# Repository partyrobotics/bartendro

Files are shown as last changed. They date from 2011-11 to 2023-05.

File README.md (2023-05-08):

Introduction
============

Programs for the various systems of the Bartendro drink dispensing robot.

Created by Pierre Michael and Robert Kaye
Copyright (c) Party Robotics 2010-2013

All of the source code in this repository is licensed under the GNU Public License 2.0.
The hardware schematic and layouts are licensed using the Creative Commons 
Attribution-ShareAlike 3.0 Unported license.

The source tree is laid out as follows:

hardware -- schematics and layouts for the dispenser and router hardware boards
firmware -- source code (C) for the dispenser and router boards
scripts  -- scripts to make running the bartendro software easier
tsb      -- legacy code from our old skool drink bot prototyp Tequila Sunrise Bot
ui       -- web interface for the bot, written in python.

These various subdirectories may contain more README and COPYING files.

Downloading updated SD Card images
==================================

In 2021 the SD card images were updated. They can be downloaded here:

https://github.com/partyrobotics/bartendro/releases/tag/v-2021-05-21

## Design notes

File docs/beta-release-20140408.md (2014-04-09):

Upgrade instructions for Bartendro software beta 2014-04-08
===========================================================

This software release is BETA quality, meaning that you may encounter bugs in the software.
Please do not use this for important parties. :)

If you find problems with the new software, please report them here:

https://github.com/partyrobotics/bartendro/issues/new

**REALLY IMPORTANT NOTES -- Please read the following before proceeding!**

* PLEASE READ THE WHOLE INSTRUCTIONS BEFORE YOU BEGIN!
* We recommend using a separate empty 4GB SD Card for this beta release. **WE DO NOT
RECOMMEND THAT YOU OVERWRITE YOUR CURRENT BARTENDRO SD CARD!!**

Download the beta release
-------------------------

To start, download this file:

ftp://download.partyrobotics.com/pub/partyrobotics/bartendro/images/beta-release-20140408.zip

Alternatively, if you know how to use 7zip, you can download this much smaller file:

ftp://download.partyrobotics.com/pub/partyrobotics/bartendro/images/beta-release-20140408.7z

While one of the above files downloads, fire up your Bartendro and go to the options tab
in the admin interface for Bartendro ( /admin/options ). You should do this using a laptop or a PC
so that you can download Bartendro's database and save it to your machine. On the options
screen, look for the Database box and then click on the "Download Database" button. This will cause
the Bartendro database file to be downloaded to your local computer. Save this file in a location
where you can find it later. Ideally, drop it into something like DropBox for safe keeping.

When the download of the software update finishes, extract the .img file by double clicking on
the .zip file. Most modern OSes will extract the .img file and place it into the same directory
where you downloaded the zip file. For the new step, you'll need a separate 4GB SD card like
this one:

http://www.amazon.com/SanDisk-Ultra-Class-Memory-SDSDU-032G-AFFP

We recommend SanDisk (they fail less often) and the speed class 10 -- this will make your Bartendro
run nice and fast. You may also use a larger capacity SD card, but it won't make a real difference 
how Bartendro runs.

Write the image to the new SD Card
----------------------------------

Next, write the image you downloaded onto the SD Card. These instructions cover all the bases for
getting this job done. Please note that you can skip the part about "Downloading an Image", "Choose
your Operating System" and "Choose your distribution". You're going to write the .img file you've 
already downloaded. Other than that, follow these instructions exactly:

http://learn.adafruit.com/downloads/pdf/adafruit-raspberry-pi-lesson-1-preparing-and-sd-card-for-your-raspberry-pi.pdf

Install the new SD Card into Bartendro
--------------------------------------

Once you've managed to write the SD Card, you're ready to swap out the current SD Card for the one
in your Bartendro. IMPORTANT: Turn off your Bartendro. If you fail to turn off your Bartendro before
swapping out the cards, you're going to damage the Raspberry Pi that runs everything. 

**AGAIN: Turn off Bartendro. In fact, unplug it from wall-power!**

If you have a Bartendro 7 or Bartendro 15, it might be easier to perform the next step with Bartendro
set upside down on its head. This next step is somewhat fiddely, due to the limited space inside the
bot.  TIP: Grab a camera(phone) and take a picture of the underside of your Bartendro to see where
each of the black cables connect to. This way you can reconnect all the cables into the proper place.
Bartendro 1 & Bartendro 3 are a cake -- the Raspberry Pi board is easily accessible in the back.

Here is a view of my Bartendro 7's SD Card:

https://www.flickr.com/photos/mayhem/13743267415/

In order to get access to the SD Card, you may need to disconnect a few dispenser cables as I did. Once
you have access to the SD Card, remove the SD Card be sliding it to the right. It should pop right out. But,
be careful! The holder for the SD Card is quite fragile and I've managed to break a Raspberry Pi that way.
Take the existing card and set it aside in some place safe. I would suggest getting a plastic bag if you
don't have an SD Card case handy. Label the bag so you can remember what this SD Card is!

Once you've set aside the old SD Card, insert the newly written SD Card into the SD Card slot in the Raspberry
Pi. Again, be careful to not damage the Raspberry pi. Make sure the card is slid all the way to the left
so that it is seated properly.

Finally, reconnect any dispensers you may have disconnected, taking care to connect the dispensers
back into the appropriate sockets. Refer to the picture you too previously in case you have any questions
as to where each cable should go. Then, turn Bartendro back upright if you turned it upside down. Then connect 
power and boot Bartendro. 

Once Bartendro is up and running, return to your laptop and go back to Bartendro's admin interface and open
the Options page. Ihe Database box, click the red "upload a database" button and follow the instructions to
upload the bartendro.db file that you downloaded earlier. After this Bartendro will reboot and your Bartendro
software update should be complete.

Bartendro is now ready to use again. 

Reporting bugs
--------------

If you find any bugs (issues), please report them here:

https://github.com/partyrobotics/bartendro/issues/new

If you run into trouble during this update, give us a shout here: http://partyrobotics.com/contact-us/

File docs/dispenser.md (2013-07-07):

Documentation for Bartendro Dispenser

Functional overview
===================

The Bartendro Dispenser can dispense liquid with milliliter accuracy and can be 
used in a stand alone system or in combination with a router and other pumps to create a more
complex liquid dispensing system.

The functions this dispenser can perform are:

- Run the pump for a number of milliseconds.
- Run the pump for a number of rotations (or quarters of rotations)
- Set the built-in LED colors and run LED animations
- Estimate the amount of liquid left in a bottle
- Sense when the pump is seizing and shut off power to the motor
- Track use of the pump using number of rotations.

Hardware overview
=================

Bartendro uses a star network topology using RS-232 (serial) communications.
A Bartendro drink bot usually contains a Raspberry Pi (RPI), a router board for communicating 
with dispensers and up to 15 dispensers. Using the router, the RPI can select one dispenser at
a time and communicate with it or communicate in broadcast mode to all of the dispensers at the 
same time. 

While these docs focus on discussing the dispensers, you need to be aware of what the router
does in order to fully understand all of the communication nuances of our dispensers. Because
of the router, each dispenser is programmed with a dispenser id that uniquely identifies a 
dispenser in the system. This id needs to be received from the dispenser at the start of the 
communication with the dispenser.

Each dispenser also contains 4 tri-color LEDs connected to a WS2801 LED driver chip that handles
the PWM functions to set the LEDs to a given color. All LEDs in one dispenser are connected
to one WS2801 chip and cannot be independently addressed. Given that the RPI cannot communicate
with all of the dispensers at exactly the same time, we've included a SYNC signal from the router
to each of the dispensers. This SYNC signal is used to synchronize LED animation patterns
stored in the dispensers. The dispenser changes the color of the LEDs based on the stored
pattern periodically based on the SYNC signal.

Accuracy considerations
=======================

Pumping speed and accuracy are sometimes in conflict. 

For instance, if you are dispensing 10ml via the dispense ticks method at full speed (speed 255), 
you are likely to get about 2ml more output that you asked for. The reason for this is that the
motor requires more time to spin down from full speed once the desired number of ticks is reached.

Rather than forcing one method on all of our users, we ask you to consider the proper handling
of this quirk of our dispensers. We suggest the following methods:

1. The ostrich solution: If you care about dispensing larger volumes and being off by 2ml is not a 
problem, then don't worry about it.

2. The sloppy method: Dispense 2ml less at full speed than you actually plan to dispense. This should
work out ok, but its... sloppy.

3. The slow, but sure method: Reduce the speed to half speed. The "overpour" will be negligible and your
output will be correct, but slower.

4. The corporate american way: Dispense your desired amount at full speed, less 10ml. For the last 10ml,
dispense at half speed. This is how the oil companies ensure they don't give you one cent of gas too much. :)

IMPORTANT NOTE: The above instructions assume that you provide the pump motor 24V. If you provide
less voltage your results may differ and you should test the results accordingly.

Communicating with a dispenser
==============================

After power up, the LEDs in the pumps will turn blue, waiting for communication. If a pump 
starts up and has a solid red color, its is missing a dispenser id that needs to be 
programmed into eeprom. See eeprom section for more information on this.

To initiate communication, the user should send the question mark character '?' to the pump. 
The dispenser will respond with a one byte response that is its dispenser id. The dispenser 
will continue to respond to '?' characters until it receives a 0xFF character, indicating that 
the dispenser user has captured the dispenser id and communication can start. The user should 
save the dispenser id as it will be required to address the dispense in subsequent communication.

Once the dispenser is ready for communication it will display its "idle" LED pattern which is a 
rainbow color changing pattern. At this point the dispenser is ready to receive a packet
of data. Now the user may send a packet of data to the dispenser. The dispenser will respond
with either a single byte ACK code, or a complete packet, depending on the type of
packet that was sent.

Each packet contains a destination field, which is the dispenser id that was captured
in the beginning of communication with the dispenser. While this may seem silly in a single
dispenser setup, its important when more than one dispenser is used in conjunction with 
a router. All packets sent from the router are sent over one serial TX line to ALL dispensers
connected to the router. All dispensers receive the packets and if the packet is not
marked as a broadcast packet or marked with its dispenser id, the dispenser will ignore
the packet. If a dispenser receives a packet that is a broadcast packet it must take the
appropriate action and NOT SEND a response. Broadcast packets should NEVER be replied to. 
If a dispenser receives a packet with its dispenser id, it must take action and then 
send a response to the user. Depending on the packet type, a response can either be 
a single character ACK code, or a complete packet in response.

For more information on how packets are structured, packet types and if they require
a response, see the detailed packet sections below.

Packet structure
================

Packets are comprised of two sections:

 * Header: 2 characters, always 0xFF 0xFF
 * Packet body, which is 7 bit data escaped, 10 bytes long

This packet body must be encoded into 7 bit data, so that the MSB of any data in the packet will
never be set. This allows the dispenser to clearly identify a packet header, which is the 
only data to ever have the MSB set in an entire packet. For details on how to encode data
to 7 bits, please see firmware/common/pack7.c[|h]. 

The data in the packet, when unpacked is 8 bytes long:

 * unsigned byte: destination dispenser id -- the dispenser id discovered during the 
   communication setup or BROADCAST_DEST.
 * unsigned byte: packet type -- one of the packet types described below
 * 4 bytes of payload data -- Either a 32 bit value, 2 16 bit values or 4 8 bit values.
 * unsigned 16 bit word: 16 bit CRC value calculated for the destination, type and payload
   value. For the details of this algorithm, see the function crc16_update() in
   ui/bartendro/router/driver.py

Sending packets
===============

Packets should be sent to the dispensers with a baud rate of 9600, no party and 1 stop bit.
After sending 10 bytes, the user should wait until the dispenser sends a response. Most packet 
types will get a single byte ACK code response and some will get a complete packet as a response.
Packets that receive a full response are:

 * PACKET_IS_DISPENSING 
 * PACKET_LIQUID_LEVEL
 * PACKET_UPDATE_LIQUID_LEVEL
 * PACKET_SAVED_TICK_COUNT
 * PACKET_GET_LIQUID_THRESHOLDS

All other packet types will receive a simple ACK code, consisting of one of the following:

 * 0 - PACKET_ACK_OK       -- packet received OK and acted upon
 * 1 - PACKET_ACK_CRC_FAIL -- packet data was corrupt and was not executed
 * 3 - PACKET_ACK_INVALID  -- the packed was improperly packed to 7 bits and did not yield 8
                              bytes of packet data.
 * 4 - PACKET_ACK_INVALID_HEADER -- an incomplete header (only one 0xFF character) was received
 * 5 - PACKET_ACK_HEADER_IN_PACKET -- An header character (0xFF) was received in a packet, 
                                      which is invalid.

For any packet that requires a complete response (any packet that returns data and not just an 
ACK) the dispenser will respond by sending a complete packet in response. Once this packet has
been received by the user, a single character ACK, as described above, must be sent to the
dispenser.

Packet types
============

The following packets can be set to/from the dispenser:

* PACKET_PING -- A diagnostic to see if the dispenser is alive. No action is taken. Contains
  no data payload.
* PACKET_SET_MOTOR_SPEED -- Turn the motor on at a given speed. The max speed is 255, which 
  should be suitable for most applications. If you'd like the dispenser to turn more slowly, 
  you can give it a slower speed. Slower speeds can be useful for dispensing smaller quantities
  of liquid or where more fine grained control is required. We recommend to not set the speed
  below 64, since at that speed the motor can barely overcome the friction to turn the pump.
  To turn the pump off completely, set the speed to 0. Once this command is initiated, the 
  dispenser will immediately return an ACK and it will not wait for the dispense function to 
  complete. Data payload is motor speed as a 8 bit unsigned int in the first byte and wether
  or not to enable over current sense in the second 8 bit unsigned int.
* PACKET_TICK_SPEED_DISPENSE -- Dispense for a certain number of ticks at a given speed. Dispenser
  rotation is measured in "ticks" which are generated by magnets moving over hall sensors in the 
  dispenser. There are 4 hall sensors, so it takes 4 ticks for the pump to make one full turn. 
  This function is the most accurate way to dispense a liquid. We've determined that the pump 
  dispenses 1 milliliter in 2.78 ticks. Once this command is initiated, the dispenser will 
  immediately return an ACK and it will not wait for the dispense function to complete. The number
  of ticks to dispense is an unsigned 16 bit payload and the speed to dispense (max speed is
  255!) is the second unsigned 16 bit payload.
* PACKET_TIME_DISPENSE -- Dispense for a certain number of milliseconds. The 32 bit payload
  determines the number of milliseconds the pump should run for. Tick counting is completely
  ignored with this command. Payload is a 32 bit unsigned integer.
* PACKET_LED_OFF -- Turn off the LEDs in the dispenser. No payload.
* PACKET_LED_IDLE -- Display the "idle" pattern in the dispenser. No payload.
* PACKET_LED_DISPENSE -- Display the "dispense" pattern on the LEDs. No payload.
* PACKET_LED_DRINK_DONE -- Display the "drink done" pattern. No payload.
* PACKET_IS_DISPENSING -- This function asks the dispenser if it is still dispensing. Since
  the dispense commands return immediately and don't wait for the dispense to complete,
  the user needs a method to determine if a dispense is complete. This call enables that.
  This packet requires a complete packet response. There is no data payload for the
  request sent from the user, but the dispenser responds with a boolean response (is dispensing)
  in the first byte of the payload and if the over current sensor has been triggered in the 
  second byte of the payload.
* PACKET_LIQUID_LEVEL -- If a dispenser is equipped with a liquid level sensor, this call
  will return the liquid level saved in the dispenser's ram. Liquid levels are not read on 
  the fly -- instead a stored value will be returned to the user. To update the stored value 
  with the current value use the PACKET_UPDATE_LIQUID_LEVEL command. The liquid level in the 
  bottle (or whatever vessel might be used) is expressed as 10 bit value (0 - 1024). Liquid
  level sensors are sensitive devices that require a minor amount of calibration. Each liquid
  level sensor may have a slightly different idea of what "empty" means. For more information
  on how to interpret these values, please see the section "liquid level sensors". If the
  dispenser is not equipped with a liquid level sensor, the values returned by this command
  are undefined. This packet requires a full packet response. Packets sent to the dispenser
  contain no payload. Packets sent from the dispenser contain a 10 bit value in the
  first 16 bit value in the payload.
* PACKET_UPDATE_LIQUID_LEVEL -- Use this command to force the dispenser to update the 
  current liquid level. We recommend that you let at least 5ms pass between updating the 
  liquid levels with this command and reading them with PACKET_LIQUID_LEVEL. No payload.
* PACKET_ID_CONFLICT -- If two dispensers connected to one router have the same dispenser id,
  it creates an ID conflict. This command turns the pump LEDs red and cause the pump to
  do nothing until it is reset. No payload.
* PACKET_LED_CLEAN -- Set the LEDs to the "clean" pattern. No payload.
* PACKET_SET_CS_THRESHOLD -- This command sets the threshold value at which the motor is 
  considered to be seized and should be turned off. This can happen when hoses get old or
  are otherwise obstructed. To prevent the motor from burning out, the current sensor
  determines when a motor is working too hard and shuts off the pump. The default value
  programmed into the dispensers should suffice for most uses. For more information see
  the section "over current protection". The current sense limit should be given in 
  the first 16 bit value of the payload.
* PACKET_SAVED_TICK_COUNT -- This command retrieves the tick count saved in the dispenser's
  eeprom memory. It tells you how many ticks (turns if you divide ticks by 4) the dispenser
  has turned since the tick counter was reset. This feature is to measure hose life and to give
  the user of the dispenser an idea when the hoses inside the pump need to be replaced. This
  packet requires a full packet response. Packets sent to the dispenser contain no payload. 
  Packets sent from the dispenser contain a 10 bit value in the first 16 bit value in the payload.
* PACKET_RESET_SAVED_TICK_COUNT -- This command resets the stored tick count in the dispenser's
  eeprom memory. This value should only be reset when the hoses inside the dispenser have been
  changed. No payload.
* PACKET_GET_LIQUID_THRESHOLDS -- This command is used to query the liquid out thresholds stored
  in the dispenser's eeprom memory. This packet requires a full response and the response packet
  will contain two 16 bit values: "low" threshold and "out" threshold. For more information
  on liquid level thresholds, please see the section "liquid level sensors". The first
  16 bit value of the payload is the "low" threshold and the second 16 bit value is the "out"
  threshold.
* PACKET_SET_LIQUID_THRESHOLDS -- This command sets the liquid level thresholds. Two 16 bit 
  values for "low" threshold and "out" should be contained in the packet. For more information
  on liquid level thresholds, please see the section "liquid level sensors".
* PACKET_FLUSH_SAVED_TICK_COUNT -- This command should be sent to the dispenser before shutting 
  down the dispenser. The dispenser keeps track of the current tick count in RAM and only 
  flushes it to eeprom periodically to prevent the eeprom memory from wearing out. To ensure 
  that the accurate tick counts are stored in the pump, make sure to call this command before 
  shutting down the dispenser. No payload.

Deprecated commands:

* PACKET_TICK_DISPENSE -- Dispense for a certain number of ticks. Pump rotation is measured in
  "ticks" which are generated by magnets moving over hall sensors in the dispenser. There
  are 4 hall sensors, so it takes 4 ticks for the pump to make one full turn. This function
  is the most accurate way to dispense a liquid. We've determined that the pump dispenses
  1 milliliter in 2.78 ticks. Once this command is initiated, the dispenser will immediately
  return an ACK and it will not wait for the dispense function to complete. The number
  of ticks to dispense is an unsigned 32 bit payload, but only the 16 bits of data will be used.
  This command is deprecated in favor of the PACKET_TICK_SPEED_DISPENSE that allows the user
  to specify the speed with which to dispense.

EEPROM
======

The EEPROM of the Atmel atmega168a micro-controller contains the following pieces of
data:

   offset     data type         data
   0          8 bit unsigned    Dispenser id
   1          32 bit unsigned   Run count in ticks
   5          16 bit unsigned   Liquid "low" threshold
   7          16 bit unsigned   Liquid "out" threshold

To get a working dispenser, you will need at least to minimally write a dispenser id 
into the first byte into eeprom RAM. This can be any value but 0 or 255. 

Dispensers shipped from PartyRobotics have this dispenser id set. You can set another
dispenser id (chosen randomly) by running the script in /firmware/dispenser/pump.sh

Resetting the dispenser
=======================

To reset the dispenser, the user needs to hold the RESET line high for at least 1ms. This will
do a software reset that causes the dispenser to stop what it is currently doing and
enter the address discovery mode as it normally would on startup.

Liquid level sensors
====================

The liquid level sensors that are available for our dispensers allow the dispenser to
estimate the amount of liquid left in a bottle. The "liquid level" sensors are really
differential pressure sensors that measure the difference between ambient air pressure
and a liquid level hose that rests in the bottle. The liquid in the bottle exerts a tiny
amount of pressure on the hose and there for on the sensor. As the liquid level in the
bottle drops, the pressure approaches the ambient pressure. Once the pressure exerted
on the hose is equal to ambient pressure, the bottle is empty. 

Care should be given to never empty a bottle fully, because if the intake hose sucks
air while dispensing, an inaccurate dispense occurs. To avoid this, the liquid "out"
threshold should be set conservatively so that the dispenser will consider a bottle to
be empty before it is actually empty.

These sensors are sensitive devices that require some calibration. Even at ambient 
air pressure, not all sensors are going to return the value absolute value. Depending on
how you plan to use the pressure sensors we encourage you to read the pressure sensor
readings at different liquid levels to get acquainted with how the sensor works.

Over current protection
=======================

Each dispenser also comes equipped with an "over current sense" circuit. This
circuit estimates the amount of current that the motor in the dispenser consumes. If for
some reason the motor binds up and consumes large amounts of current, the dispenser
stops the motor and flashes the red LEDs quickly. At this point the dispenser refuses
to engage the motor again until the dispense has been reset. 

Empirical testing has shown that the default value of 465 works well for the motor
running at full speed. You can provide different current sense threshold values
using the PACKET_SET_CS_THRESHOLD command.

Color error codes
=================

The dispenser's only real form of end-user feedback is the color of the dispenser. The
following colors/animations are programmed into the stock dispenser:

* Solid RED at startup: id conflict
* Solid BLUE at startup: ready for communication, waiting for user to initiate 
  communication.
* Solid GREEN: A 0xFF character has been received after communication startup. The
  dispenser is now waiting for the first command from the user.
* Rainbow color animation: idle mode. The dispenser is waiting for commands from the user.
* Red <-> blue color animation: Dispenser is dispensing liquids.
* Pulsing green color animation: Dispsener is done dispensing liquids.
* Pulsing purple color animation: Dispenser is currently being cleaned. This mode really
  only has significance in the context of a larger setup where the RPI can execute
  a clean cycle using multiple dispensers.

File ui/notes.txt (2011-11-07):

Feature improvements:

- RBG Led per dispenser, programmed via SPI
- Allow a default size of a drink. (an 8oz sherpentine would be trouble!)
- Support quadarture input from the motors
- PWM support for driving motors
-

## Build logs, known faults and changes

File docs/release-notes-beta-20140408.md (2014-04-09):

Release notes for the beta version of 2014-04-8
===============================================

This is our first post-kickstarter software release. We've added a few critical new features, improved
the UI and added support for the new V3 Dispensers that will be shipping soon. 

We've made the changes listed below. If you would like to try out these changes, please see our upgrade
instructions:

https://github.com/partyrobotics/bartendro/blob/master/docs/beta-release-20140408.md

User facing features:

- We've added a "I'm feeling lucky button"
- UI consistency improvements: General improvements. Green buttons indicate that some action will occur when pressing this button!
- Minor UI tweaks and layout improvements
- Improved Shots UI, including allowing users to switch between cocktail and shot mode
- Improved trending drinks menu, giving a view of the last 12 hours, 3 days, 1 week and all time. Drinks are now clickable links to allow users to examine the drinks on the drink screen.
- For dispensing small amounts of liquids, turn the pumps slower for more accurate dispensing

Admin facing features:

- Bartendro logo goes to admin screen
- Taster button on drink designer -- this is really handy for making new drink recipes.
- Improved clean cycle that runs all pumps for 15 seconds. Bartendro 15 can clean the pumps on the left side indepdenently from the pumps on the right side.
- Rewritten Bartendro Mixer, which is the heart of Bartendro. This should fix a number of liquid level bugs and give better overall stability
- If v3 dispensers are installed, then a "reverse" button appears on the dispenser admin page.
- Display network IP addresses that Bartendro has on the options screen
- Added an option wether or not to show the shots interface.
- Added an option wether or not to show the "I'm feeling lucky!" button
- Used better visual cues in the dispenser view to show the liquid level for each dispenser (if enabled)
- Improved wording of the database upload/download feature

Firmware changes:

- Created updated firmware for v3 Dispensers.
- v3 Dispensers will be able to run pumps in both directions.
- Implemented version checking in firmware

Issues fixed in this release
----------------------------

The following issues have been closed for this release:

https://github.com/partyrobotics/bartendro/issues?milestone=3&page=1&state=closed

Issues still open before release:

https://github.com/partyrobotics/bartendro/issues?milestone=3&state=open

If you find any problems with this release, please report them here:

https://github.com/partyrobotics/bartendro/issues/new

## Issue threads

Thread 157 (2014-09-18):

Intermittent Proper Dispenser Detection

pmich, 2014-09-18:
Someone has mentioned that their bot does not detect all their dispensers 100% of the time. Out of 15, sometimes it detects 14, or 13, or 12. They have to restart many many times for the bot to detect all 15, but in the end it usually works. After much experimentation, I've actually been able to recreate the bug on a brand new router board. It is still intermittent in nature, but it happens more often than not. My setup is B15 with 2 v3 dispensers with IDs: B3 and AB. The first symptom is that on power up the dispensers flash blue 3 or 4 times, then turn red. However, the dispensers always get into the color fade mode once the bot is booted, so that's confusing because it seems like everything is ok. Once I go into the debug menu I see that the the IDs are conflicting and that dispenser v2 was detected.
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
The dispensers work fine on another board, and if plugged in individually, their ID value is more often read correctly in the debug screen. If both dispensers are plugged in, it seems that about 30% of the time both dispenser IDs will be read correctly, otherwise they will display a conflict with ID 63 and v2 detection.
I decided to capture with a logic analyzer to see what was going on. I've reduced down to a single dispenser, and this is what it looks like on startup (orange is TX from Router, red is TX from dispenser):
After a faulty start, this is what it looks like on when I hit 'reset dispensers' from the dispenser page:
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
This is what it looks like when I hit 'test dispensers' in the debug page:
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
On boot (zoomed on the very first thing):
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
On boot (zoomed all the way out):
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

After a power cycle, I got a different result.
On boot it actually got one of the IDs correct:
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
The is what 'test dispenser' from the debug page produces:
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

I know we had a software bug at one point that was timing related, but I don't know if this is similar, I'd love to get your thoughts.

Other than chucking this in the dead router board pile, is there some test to further verify the state of the router board and know that it really is bad, and more importantly, how do we test for a problem like this before we ship hardware out? Should / could we make the dispensers display a different pattern if their ID is never read correctly by the router?

pmich, 2015-01-10:
This issue has been resolved. The dispensers were found to be entering into text-mode inappropriately. A dispenser firmware update requiring 3 consecutive '!' to get into text mode did the trick.

robotskirts, 2015-10-09:
My machine is exhibiting this behavior. How do I update the dispensers?

partyrobotics, 2015-10-13:
Hi Eliot,

Please follow the instructions here:
http://support.partyrobotics.com/Guide/Re-programming+a+Dispenser/13

Best,
-Pierre

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

nighteagle1974, 2017-04-27:
Hello,

so the last dispenser-firmware linked in the above post is older than the post from pmich tell us the trick is to have 3 consecutive "!" to get into Text-Mode. I have compared the Sources from 2015 and 2016 all the same except the LED-Swapping and Software-Revision-ID.

I have the same behaviour with the newer Firmware from Oktober 2016. I have compiled with the raspi2 and avr-gcc and avrdude and program the dispenser are fine. Set ID also fine... Solder Jumper to Version 4 and boot bartendro pumps are recognized as Version 4.. only on the first Slot.
I use for testing only two pumps on Slot 1 and Slot2 both Revision 4 with firmware from Git.
But often the Pumps are not recognized in the Bartendro-Debug Window, when i press button dispense 10ml under Dispenser Menue then sometimes the pump do not start and Error 502 come back. In debug window i see Dispenser V2 detection of first pump. If i change the pumps the next time also first pump detect V2. So here is an bug by detection the First Pump? Slot 1?

To prevent Text-Mode swapping ( we only need the binary-Mode for communicate with the router?) can i change something on the dispenser-sources? Deactivate Text-Mode?

Regards

nighteagle1974, 2017-04-28:
Hello again,

so i have a look into the Sources of the Router.

1. I see the Baudrate is not correct calculated:
#define UBBR             (F_CPU / 16 / BAUD - 1)
Here 52,08
See in Datasheet Atmel:
((F_CPU + UART_BAUD_RATE * 8L) / (UART_BAUD_RATE * 16L) - 1)
Here 51,58

2. Router.c
For what you use the g_reset ?
I see is writing High and Low but is not use for some logic?
Then if we don't use the g_reset we don't need this:
`            cli();
            reset = g_reset;
            sei();

            if (reset)
            {
                cli();
                g_reset = 0;
                sei();
                break;
            }`

Because we break the ISR for an nonsense writing of g_reset ?

I see the echo_dispenser is call by an ISR. So on the beginning of  the ISR the reti is disable ISR and enable ISR at the end. If you call the echo_dispenser in the ISR:
`ISR(PCINT0_vect)
{
    echo_rpi();
    echo_dispenser();
}`

There is no break of these function like you wrote here:
`void echo_dispenser(void)
{
    volatile unsigned char *group;
    uint8_t pin, state;

    // capture a local copy of g_dispenser to guarantee the next two lines use the same value
    // (interrupt could come between the two and change g_dispenser, I think? Depends on interrupt
    // rules. I don't *think* this is an issue, but it would be a rare enough failure case that
    // it would be near impossible to debug.)
    uint8_t disp = g_dispenser;

    group = dispenser[disp].group;
    pin = dispenser[disp].pin;

    state = *group & (1 << pin);

    if (state)
	// Bit 0 go High
        sbi(PORTB, 0);
    else
	// Bit 0 go Low
        cbi(PORTB, 0);
}
`
I think we don't need write globale variable to an locale variable into an ISR-called Function.

What your thoughts about my Points?

nighteagle1974, 2017-04-28:
Looks like the Code-Comment is not working here on this Github?
`Test Code-Comment`

nighteagle1974, 2017-04-28:
Looks like the Code-Comment is not working correct here on the Github?

mayhem, 2017-04-28:
g_reset is used to reset the each pump on the bot -- it is a critical function. A message comes in via I2C to reset the bot which gets acted on here:

   https://github.com/partyrobotics/bartendro/blob/master/firmware/router/router.c#L240

Why do you think the ISR is broken by writing to a variable? The variable is defined as volatile, so I see no problems with it. Have you tried any of the changes you are suggesting? Do they improve things?

nighteagle1974, 2017-04-28:
No i don't think ISR is broken.
The Programmer write here:
// capture a local copy of g_dispenser to guarantee the next two lines use the same value
// (interrupt could come between the two and change g_dispenser, I think? Depends on interrupt
// rules. I don't *think* this is an issue, but it would be a rare enough failure case that
// it would be near impossible to debug.)

But does is not correct because the ISR is deactivated bei reti from CPU, you don't need to write the global to an locale in an ISR-Called function.
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
nighteagle1974, 2017-04-28:
Okay.. i see now more..

You have an For-Loop to test reset-variable.. if there is High you break the Loop and go to one Level higher and there is the reset-dispenser functions. Okay i understand.

mayhem, 2017-04-28:
"3.3V Pegel" bissu deutsch? :)

long Cables 0,5m -- yes, I've heard of this problem before of bots that do not use Bartendro cases (ergo longer cables are needed). I would love to hear if this makes any difference in communication reliability. Also, do you have problems while the motors are running (interference) or also when motors are not running?

nighteagle1974, 2017-04-28:
Ja Deutsch.. meinte 3,3V Level :-)

mayhem, 2017-04-28:
Klar, schon kapiert. :)

nighteagle1974, 2017-04-28:
Yes have Problems like pierre wrote above. I 'm looking now for.. first 3,3V level is an problem by cables longer 0,5m. Sometimes Pumps not recognized correct. I have to restart bot many times. Actually i will check communication with logic analyzer.

nighteagle1974, 2017-04-28:
Toll, wenn ihr alle Deutsch seid. Warum sieht man das nicht :-)

mayhem, 2017-04-28:
Ich bin deutsch, aber auch nur der einzige. :) Und ich habe auch zu lange in Kalifornien gelebt...

I would love to hear if you can find problems on the logic analyzer -- I've never had a Bartendro with longer cables, so I've never really seen this problem.

nighteagle1974, 2017-04-28:
Cool... bei Arnie?

Yes  the 3,3V is an Problem for UART with cables. If you have some other cables it may can work but in other situations it can't work correctly. This is why some people have problems and some not -  i think.

mayhem, 2017-04-28:
Ja, bei Arnie. :)

But, I do wonder if the UART calculation will make any difference -- I'd love to hear about it.

mightybigcar, 2017-04-28:
OK, I'm just an embedded software guy who can't even reliably read a schematic, but the I2C discussion reminds me of something I've bumped into in previous projects with long I2C lines (that is, over about 100mm).  In my experience (which may or may not apply here), for long distance, I2C gets finicky about trace/cable resistance, capacitance, noise, and so on.  You may need to add an active pull up on the line, or tweak the UART configuration (if possible), or switch to shielded or twisted pair cables, or some combination of these.  Anyway, I think this tends to confirm nighteagle1974's concerns about 3.3V on the longer cables - the next thing I'd do there is bring in a EE to check that and maybe add a pull-up (or try to configure stronger pull-up on the UART).

nighteagle1974, 2017-06-23:
Moin Robert,

habe wieder etwas Zeit gefunden für den  Bartendro.
Habe Einges verändert.. jetzt geht es wohl gut... zumindest keine
Störungen mehr in der kommunikation.

Eine Frage kurz zur Software.. Ui wenn man Coktails selber erstellt was
bedeutet dann die Angabe "Parts" für die einzelnen Zutaten?
Sind das cl oder Prozente von der Gesamtmenge die man ja einstellen
kann, bei mir 150ml Drinkgröße?

Wobei das ja auch nicht passt.. dann müssten ja immer im Ergebnis 10
parts rauskommen..
Gibt ja auch Cocktails die haben 12 parts insgesamt... Irgendwie blicke
ich es nicht.

Grüsse,

Borris

Am 28.04.2017 13:42, schrieb Robert Kaye:
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

nighteagle1974, 2017-10-21:
Moin,

sag mal kannst du mir ev. weiterhelfen bei der Frage wo in welchen Files
ich suchen muss, dass ich die dosierten Mengen der Ingredients finde?
Also irgendwo wird ja auch für das Trending die dosierten Mengen
kalkuliert!?

Ich möchte die dosierten Mengen speichern und von einem vorher
festgelegten Wert abziehen.

z.B. Alle Zutaten sind in 1L Flaschen - dann setze ich eine Variable für
jede Zutat i.e.   bootleSizeIDn = 1000ml; (n=1-15)
Dann wenn ein Drink gemacht wird - sind ja die Dosiermengen bekannt -
also ziehe ich die jeweiligen dann von der bootleSizeIDn ab.

Bei einem Shot dann einfach 1000ml -30ml = 970ml also hat bootleSizeIDn
dann irgendwo nur 970ml.
Damit könnte man dann eine Grenze setzen wenn bottleSize unter 100ml
fällt, das dann eine Meldung kommt das die Flasche gewechselt werden muss.

Das scheint mir einfacher und zuverlässiger als der Liquid-Sensor zu sein.

In dem Forum bzw. Answer-Bereich passiert so Wochenlang nichts :-(

Grüsse,

Borris

mayhem, 2017-10-24:
> Das scheint mir einfacher und zuverlässiger als der Liquid-Sensor zu sein.

Das stimmt — das ist uns erst viel zu spät aufgegangen.

Leider ist diese feature etwas mehr arbeit — die datenbank muss erweitered werden und neue benuzter oberflächen müsse gebaut werden…

Hier ist aber ein guter anfang:

  https://github.com/partyrobotics/bartendro/blob/master/ui/bartendro/mixer.py#L91

Closed 2015-01-10.

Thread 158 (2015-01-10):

Database Upload Not Working Properly

pmich, 2015-01-10:
Several weeks back I added many ingredients and drinks to my bot and downloaded bartendro.db to my DropBox account. I renamed the file to be bartendroDec2014.db. Today I tried uploading that database file from the options tab. After, the file is uploaded, I get a message saying that the new database file has been successfully uploaded. However when I go to the drinks page, the new drinks are not present. Also, when I go back to the 'upload database' button, it says that the current database file is bartendro.db instead of bartendroDec2014.db like it should be. I've tried 'save and reboot' from the options screen, and I've even tried naming the file back to bartendro.db and uploading that, but all the newly added stuff still doesn't show up. I could've sworn this worked before. Thoughts?

OnkelOlli, 2015-01-10:
After adding new drinks and ingredients, and saving every time, you need to
reboot via the options menu. Then, the additions are used correctly and
will show up in the menu, and only then you can export the new  database.
If you do not reboot, somehow the old settings will be exported.
Greetings, Olli
 Am 10.01.2015 21:49 schrieb "pmich" <notifications@github.com>:

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

nighteagle1974, 2015-12-04:
Hi,

have somewhere an working rpi B+ image?
I think the Image is onyl for RPI B old Version and ist not booting for an B+ RPI.

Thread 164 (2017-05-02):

Liquid level sensor triggered for one ingredient, breaks all dispensing.

pmich, 2017-05-02:
Garran: I am trying to use the liquid level sensors on my Bartendo, but I am running into an issue. If one ingredient runs out it won't let me make any of the drinks. It gives a message saying "Bartendro has hit a snag and can't make drinks right now." Do you know what is going on here? Thanks!

Pierre: Might be worth checking the calibration values and making sure they're sane. Also, make sure that the ingredient that's running out (pretend it's vodka) isn't used by every other drink in the menu.

Garran: Yeah, the values are good. I can look at the dispensers and it shows that only one ingredient is empty (pretend it is vodka). It removes all drinks which require vodka from the menu. When I try to dispense a drink which doesn't contain vodka it lets me adjust the drink and when I hit pour it flashes the "now serving" popup which is immediately replaced with a message "Bartendro is broken. Bartendro has hit a snag and can't make drinks right now. Sorry!" I have tried power cycling it, and that doesn't change anything.

RPI B v. 1
software version is 20140501

ggossage, 2017-05-02:
The ingredient which has run out does not appear in the shots menu, which makes sense. All other ingredients CAN be dispensed from the shots menu. It is only the mixed drinks which can't be dispensed.

ggossage, 2017-05-03:
Updated software to 20151103. Issue appears to behave exactly the same as before.

Debug log:

Bartendro start up sequence:
Opening /dev/ttyAMA0
Done.

Opening I2C bus to router
Done.
Discovering dispensers
port 0:
  E7 E7 E7  -- Found dispenser with pump id E7, index 1
port 1:
  33 33 33  -- Found dispenser with pump id 33, index 2
port 2:
  BE BE BE  -- Found dispenser with pump id BE, index 3
port 3:
  61 61 61  -- Found dispenser with pump id 61, index 4
port 4:
  87 87 87  -- Found dispenser with pump id 87, index 5
port 5:
  F1 F1 F1  -- Found dispenser with pump id F1, index 6
port 6:
  29 29 29  -- Found dispenser with pump id 29, index 7
port 7:
port 8:
port 9:
port 10:
port 11:
port 12:
port 13:
port 14:
Detected dispensers version 2. (Only checked first dispenser)
mixer.check_liquid_levels: check levels
dispenser 0 level: 71 (stored: 0)
dispenser 1 level: 150 (stored: 0)
dispenser 2 level: 123 (stored: 0)
dispenser 3 level: 157 (stored: 0)
dispenser 4 level: 152 (stored: 0)
dispenser 5 level: 139 (stored: 0)
dispenser 6 level: 114 (stored: 0)
Checking levels done. New state: 0
mixer.check_liquid_levels: check levels
dispenser 0 level: 72 (stored: 0)
dispenser 1 level: 149 (stored: 1)
dispenser 2 level: 122 (stored: 1)
dispenser 3 level: 156 (stored: 1)
dispenser 4 level: 153 (stored: 1)
dispenser 5 level: 139 (stored: 1)
dispenser 6 level: 113 (stored: 2)
Checking levels done. New state: 0
Current state 6, event 0. No next state.

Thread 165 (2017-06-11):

Change in LED lights

sdnavin, 2017-06-11:
Is it possible to take control of the LED lighting color?

mayhem, 2017-06-12:
Only via reprogramming the firmware on the pumps, which needs to be done in C and requires a firmware programmer. (overall not an easy task, sadly)

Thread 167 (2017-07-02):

Liquid level sensor

sdnavin, 2017-07-02:
Hi,
I want to know how can i install the liquid level sensor and how the connection works , Please guide me on this.

pmich, 2017-07-05:
Please view instructions here:
http://support.partyrobotics.com/Guide/Installing+a+Liquid+Level+Sensor/11

sdnavin, 2017-07-06:
Hi @pmich This instructions is fine, We did this already but we have problems in that

The current Setup is we have two tubes going to the input drink, One from liquid level sensor and another from the dispenser IN. I believe this setup is fine, Now when i try setting the liquid level in the interface, the value i am getting - "4" all the time.

Debug log as follows :

Detected dispensers version 4. (Only checked first dispenser)
mixer.check_liquid_levels: check levels
dispenser 0 level: 4 (stored: 0)
Checking levels done. New state: 0
mixer.check_liquid_levels: check levels
dispenser 0 level: 4 (stored: 0)
Checking levels done. New state: 0
send_packet: Invalid ACK code 255
Failed to read liquid level threshold from dispenser 1

pmich, 2017-07-06:
The order of operations matters. You should slowly insert the dry tube (after it has already been attached to the liquid sensor), into the liquid, this is how you build positive pressure relative to ambient.

In the Liquid Sensor tab of the admin UI, you should be able to calibrate the value and see it on the spot, if you move the height of the tube relative to the liquid and you don't see calibration value changing, then there's a chance that the sensor is not plugged in all the way, or it is possibly damaged in some way.

If you have a multi-meter, you can measure the output voltage on pin 1 (while it is plugged into the dispenser and powered) and see if the sensor is functional.

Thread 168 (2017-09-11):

Got this error while installing bartendro

jaysonvalentino, 2017-09-11:
Traceback (most recent call last):
  File "./bartendro_server.py", line 118, in <module>
    app.driver.open()
  File "/home/pi/Desktop/bartendro/ui/bartendro/router/driver.py", line 173, in                                                                                                                                                              open
    data = self.ser.read(3)
  File "/usr/lib/python2.7/dist-packages/serial/serialposix.py", line 460, in re                                                                                                                                                             ad
    raise SerialException('device reports readiness to read but returned no data                                                                                                                                                              (device disconnected?)')
SerialException: device reports readiness to read but returned no data (device d                                                                                                                                                             isconnected?)

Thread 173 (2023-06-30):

Master Password ?

NielsBar, 2023-06-30:
Hey,

 I hope you are well. I have a problem before Corona, I changed the password in the software and forgot it and unfortunately I didn't write it down. Is there a master password or can I somehow reset it? Thank you

mayhem, 2023-07-03:
If you can mount the SD card (which contains a linux partition) you and look at the sqlite database that stores the bartendro config and find the password there. Is that something you can do?

NielsBar, 2023-07-05:
Hi Robert, thank you very much, that worked. Do you still sell spare parts/machines or has everything been dissolved? I would need the boards for the pumps. How much would this cost and shipping to Germany at Umlostraße 94, 33649 Bielefeld?Thanks Am 03.07.2023 um 12:03 schrieb Robert Kaye ***@***.***>:
If you can mount the SD card (which contains a linux partition) you and look at the sqlite database that stores the bartendro config and find the password there. Is that something you can do?

—Reply to this email directly, view it on GitHub, or unsubscribe.You are receiving this because you authored the thread.Message ID: ***@***.***>

mayhem, 2023-07-05:
On Wed, 2023-07-05 at 07:43 -0700, NielsBar wrote:
> Hi Robert, thank you very much, that worked. Do you still sell spare parts/machines or has everything been dissolved?

Everything has now been dissolved. 😞

--
--
--ruaok

Robert Kaye -- ***@***.*** -- metabrainz.org

NielsBar, 2023-07-05:
I'm sorry for you, could I maybe buy used or demonstration items from you that I somehow still come parts, or maybe board plans to recreate or something? Thanks so muchAm 05.07.2023 um 16:45 schrieb Robert Kaye ***@***.***>:
On Wed, 2023-07-05 at 07:43 -0700, NielsBar wrote:

> Hi Robert, thank you very much, that worked. Do you still sell spare parts/machines or has everything been dissolved?

Everything has now been dissolved. 😞

--

--

--ruaok

Robert Kaye -- ***@***.*** -- metabrainz.org

—Reply to this email directly, view it on GitHub, or unsubscribe.You are receiving this because you authored the thread.Message ID: ***@***.***>

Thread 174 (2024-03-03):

Comm's In J2 to RPI pins

Just-Tinkering, 2024-03-03:
Hi, I am trying to connect the pump board to the RPI through the RJ45 comm's jumper J2. I found the pin-outs for the pump [here:](https://cdn.sparkfun.com/datasheets/Widgets/Bartendro_Dispenser.pdf) and I'm using [this](https://github.com/partyrobotics/bartendro/releases/tag/v-2021-05-21) updated SD card image.
However, after looking through the documentation I couldn't figure out where on my old RPI (modB-512M) does the TX, RX, Reset and Sync go.
I have come across a couple of [these](https://core-electronics.com.au/bartendro-dispenser-peristaltic-pump-and-controller.html) pumps and any help to get these pouring drinks would be greatly appreciated :)

mayhem, 2024-03-04:
TX and RX go to the serial port on the RPi that you want to use. (GPI14 and 15 for serial0). Sync can go to any GPIO pin -- the PRi should output 1ms square wave -- this is used to sync the LEDs in the pumps.

Just-Tinkering, 2024-03-05:
Thanx mayhem.
Here is what I have done so far:
Loaded the above mention SD card image and inserted into the [RPI B (Rev1)](https://pi4j.com/1.2/pins/model-b-rev1.html)
I've inserted an RJ45 plug with cable into the dispenser and connected the other end as follows:
Pin 1 - 12v
Pin 2 - 5v
Pin 4 - Pin 8 (TxD UART) [RPI B (Rev1)](https://pi4j.com/1.2/pins/model-b-rev1.html)
Pin 5 - Pin 10 (RxD UART) [RPI B (Rev1)](https://pi4j.com/1.2/pins/model-b-rev1.html)
Pin 7 - Pin 12 (GPIO1) [RPI B (Rev1)](https://pi4j.com/1.2/pins/model-b-rev1.html)
Connected the [RPI B (Rev1)](https://pi4j.com/1.2/pins/model-b-rev1.html) to a monitor via HDMI.
I also added a Wi-Fi WiPi adapter to the RPI.

When I turn the power on the dispenser lights go blue.
The monitor displays green "OK's" for everything except for:
[FAILED] Failed to start /etc/rc.local compatibility.
See 'systemct1 status rc-local.service' for details.

I can then log into the RPI directly via usb keyboard with: bartendro, hackme! but don't know what to type to test it.

I can log into it wireless with: bartendro, boosemeup but in MS Edge on win10 it says:
Bartendro failed to startup, likely due to hardware or misconfiguration issue. Cannot open serial interface to router board.

Does that [SD-Card image](https://github.com/partyrobotics/bartendro/releases/tag/v-2021-05-21) work with my old [RPI B (Rev1)](https://pi4j.com/1.2/pins/model-b-rev1.html) on Win10 via MS Edge?

I'm sorry if these questions sound a bit silly but it's been a long time since I've done anything like this and we've found a few of these new in the box and would absolutely love to bring them to life.

Thanx again,
I really do appreciate your help.
:)

mayhem, 2024-03-05:
The rc.local failure relates to the fact that it can't find a real time clock. safe to ignore.

> Cannot open serial interface to router board.

Pin 4 - Pin 8 (TxD UART) [RPI B (Rev1)](https://pi4j.com/1.2/pins/model-b-rev1.html)
Pin 5 - Pin 10 (RxD UART) [RPI B (Rev1)](https://pi4j.com/1.2/pins/model-b-rev1.html)

I don't recall the pinout of the ethernet cable, but RX should connect to TX and vice versa. Double check those or just try swapping them and see if that improves it.

Just-Tinkering, 2024-03-08:
Hi mayhem,
I swapped the RX and TX but still no go :(
Do I need a router board if I'm only testing 1 dispenser?
Is there anything I can type into the RPI to test the dispenser when wired as above and connected to a HDMI monitor and USB keyboard?
Sorry for all the questions but I'm running out of ideas for this.

mayhem, 2024-03-11:
No router is required for the single pump, correct. Have you read this document?  https://github.com/partyrobotics/bartendro/blob/master/docs/dispenser.md

Just-Tinkering, 2024-03-12:
Yes I have. It says if the lights are blue it's awaiting a response. Type '?' to get a one byte response that is its dispenser id.
The lights are blue but I can't get a response from '?'  I must admit I haven't researched how to send a 0xFF character or packet structures yet but I didn't think there would be much point if the ? character doesn't communicate. I was wondering if there was anything else I could type to test communications, if so could you quote it exactly please? Sorry if I sound a bit simple on this but I just want to make sure it's working before I get in too deep.
Thanx again for your time :)

mayhem, 2024-03-13:
OK, yes the first character should get a response, so its likely a serial comms issue. Have you enabled the serial port using raspi-config ? Do you have a logic analyzer to see what is being sent over the lines?

Just-Tinkering, 2024-03-20:
>  Maybe try using a more recent distro -- perhaps something about the serial port setup has changed in the meantime?

This is why I am using an old RPI (modB-512M) and asked if it was compatible with your image?
Which RPI would you recommend for your image?
What do you mean 'more recent distro'. Isn't that your image?
Is the '?' is typed from the keyboard connected directly to the RPI?
Sorry if my questions sound silly but I want to make sure I'm not missing anything, links and examples are greatly appreciated.
Thanx.

Just-Tinkering, 2024-03-29:
Hi Mayhem, hopefully I haven't annoyed you too much. My aim for this issue was to get foolproof instructions to set this up so someone who is not familiar with RPI's etc can get this working. For example, when you said 'try using a more recent distro', do I have to install that then install your image? I thought your image included an OS but like I said, I need 'foolproof' instructions.
I realize it was a long time ago but it seems like too good of a project to let slip away.
Much appreciated,
Just-Tinkering.

mayhem, 2024-03-29:
Sorry, life is busy right now. What I need to do is sit down with a pump and get it to work actually. For that i need a couple of quiet hours, which have been hard to come by... Next week hopefully.

Just-Tinkering, 2024-03-29:
No need to be sorry, I am extremely grateful for any help you are willing to give especially since this is a very old project. I was actually logging on to delete my last comment because I thought I was being too pushy. Take as long as you want, I absolutely agree with the busy life statement.
Thanx again,
Just-Tinkering.

mayhem, 2024-04-03:
OK, I connected a pump directly to a Raspberry Pi and I was able to  communicate with the pump. To get the connection right here are the details, looked up to be sure:

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

The schematic shows you what the wires want and the RJ45 header shows you which connection goes where:

Brown (GND) -> pin 6 (GND) (board not gpio)
Blue white (TX) -> pin 10 (RX)
Blue (RX) -> pin 8 (TX)
Orange (5V) -> pin 2

the connect with "pyserial-miniterm  /dev/serial0" which defaults to 9600 baud, which is correct. I type ? and immediately get a response of '2'. Your response would likely differ.

Key thing to remember, even though your are feeding 5V into the dispenser, the mcu on the dispenser runs at 3.3V, so the IO pins must use 3.3V, NOT 5.0V.

IHTH.

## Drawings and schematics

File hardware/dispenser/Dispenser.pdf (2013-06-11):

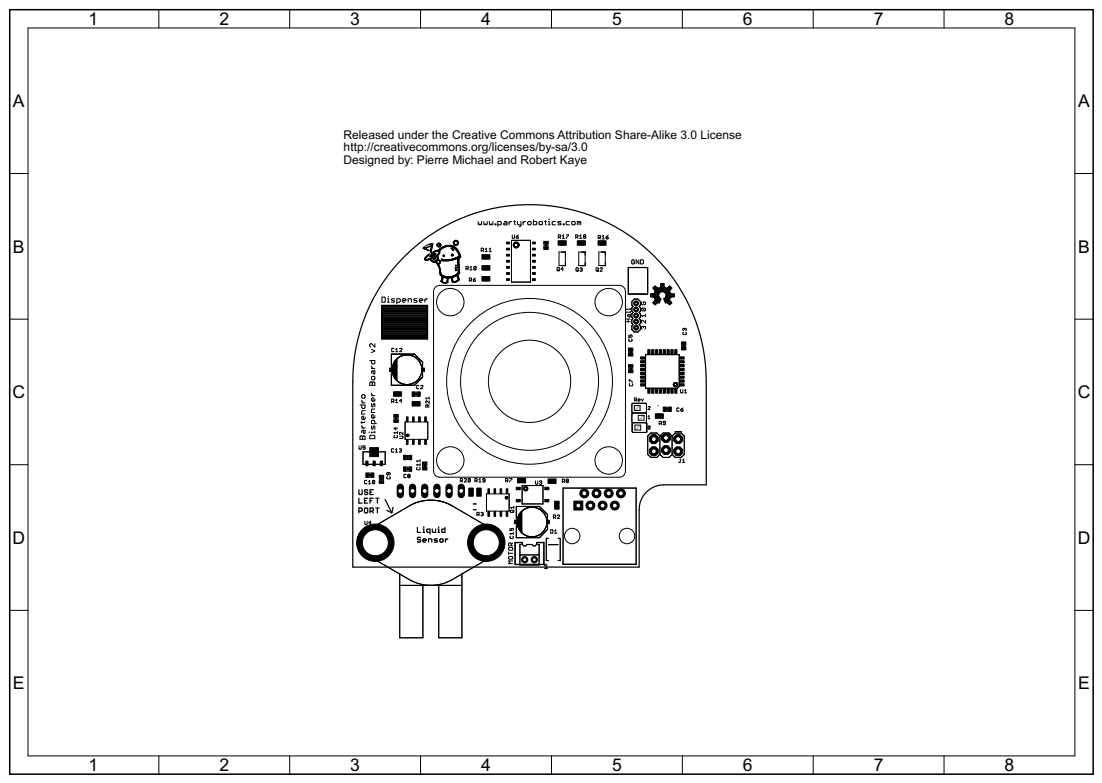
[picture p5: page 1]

Released under the Creative Commons Attribution Share-Alike 3.0 License
http://creativecommons.org/licenses/by-sa/3.0
Designed by: Pierre Michael and Robert Kaye

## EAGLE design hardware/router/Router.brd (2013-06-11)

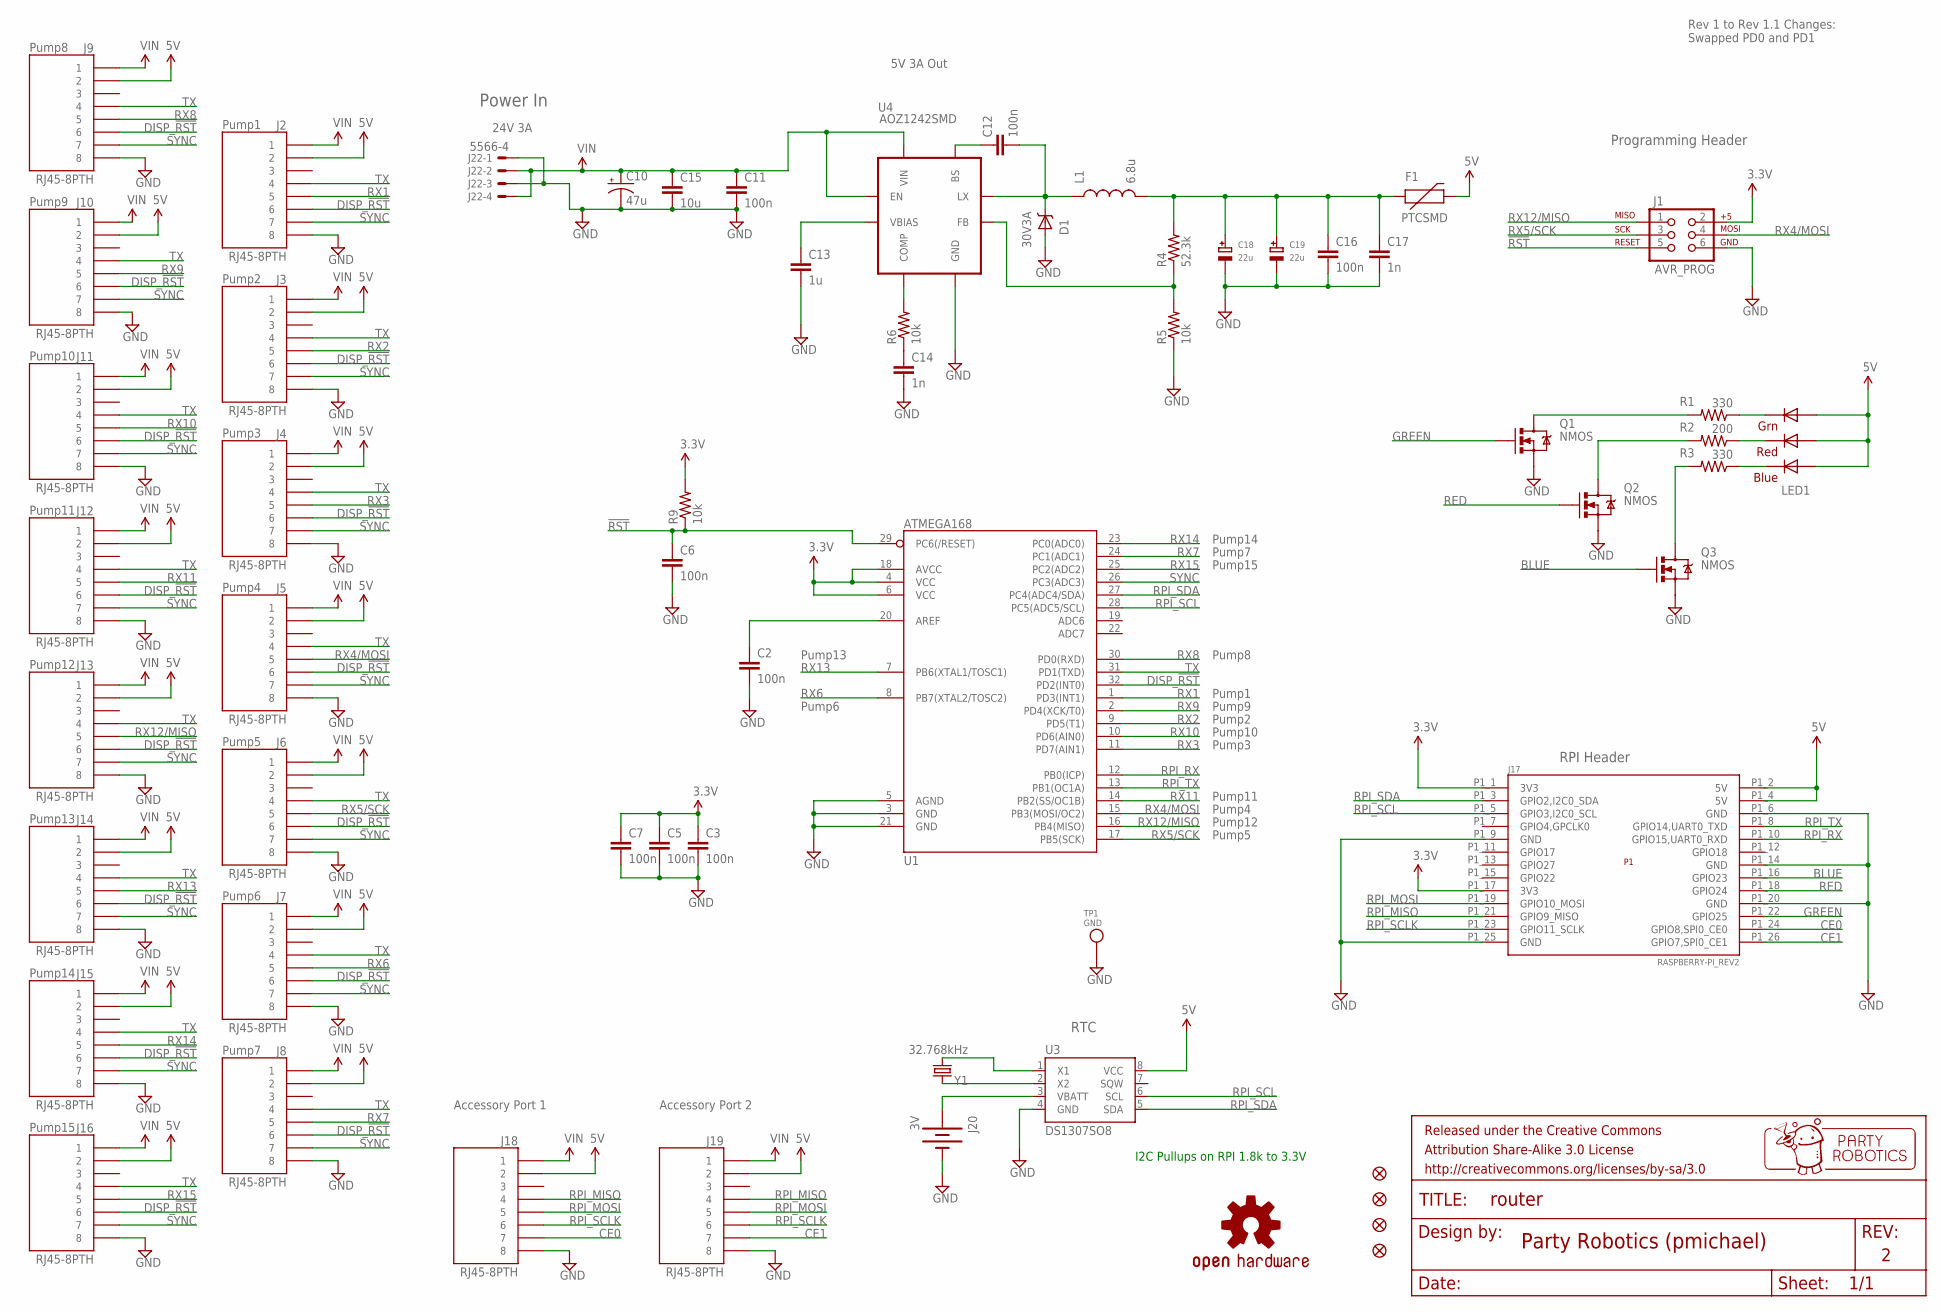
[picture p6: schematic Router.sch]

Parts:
C2, C3, C5, C6, C7, C11, C12, C16: 100n; 0603-CAP
C10: 47u; PANASONIC_D
C13: 1u; 0603-CAP
C14, C17: 1n; 0603-CAP
C15: 10u; 1206
C18, C19: 22u; EIA6032-28/C-R
D1: 30V3A; SMA-DIODE
F1: PTCSMD; PTC-1206
FRAME3: FRAME-LETTER; CREATIVE_COMMONS
J1: AVR_PROG; 2X3_LOCK
J2, J3, J4, J5, J6, J7, J8, J10, J11, J12, J13, J14, J15, J16, J18, J19: RJ45-8PTH; RJ45-8; MFG_PN A00-108-220-450
J9: RJ45-8PTH; RJ45-8
J17: RASPBERRY-PI_REV2
J20: 3V; BATTCON_12MM_PTH
J22: 5566-4
JP1, JP2, JP3, JP4: FIDUCIAL1.5X3; FIDUCIAL-1.5X3
L1: 6.8u; IND_8X8X4
LED1: RGBLED5050
Q1, Q2, Q3: NMOS; SOT23-3
R1, R3: 330; 0603-RES
R2: 200; 0603-RES
R4: 52.3k; 0603-RES
R5, R6, R9: 10k; 0603-RES
TP1: GND; TESTPOINT_SMT
U1: ATMEGA168; TQFP32-08
U3: DS1307SO8; SO08
U4: AOZ1242SMD; SO08
U$46: OSHW-LOGOM; OSHW-LOGO-M
Y1: 32.768kHz; TC26HEZ

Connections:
3.3V: C3.1, C5.1, C7.1, J1.2, J17.P1_1 (3V3), J17.P1_17 (3V3), R9.2, U1.4 (VCC), U1.6 (VCC), U1.18 (AVCC)
5V: F1.2, J2.2, J3.2, J4.2, J5.2, J6.2, J7.2, J8.2, J9.2, J10.2, J11.2, J12.2, J13.2, J14.2, J15.2, J16.2, J17.P1_2 (5V), J17.P1_4 (5V), J18.2, J19.2, LED1.1 (BLUE_A), LED1.2 (RED_A), LED1.3 (GREEN_A), U3.8 (VCC)
!RST: C6.1, J1.5, R9.1, U1.29 (PC6(/RESET))
BAT1+: J20.VCC@1 (+), U3.3 (VBATT)
BLUE: J17.P1_16 (GPIO23), Q3.1 (G)
CE0: J17.P1_24 (GPIO8,SPI0_CE0), J18.7
CE1: J17.P1_26 (GPIO7,SPI0_CE1), J19.7
DISP_!RST: J2.6, J3.6, J4.6, J5.6, J6.6, J7.6, J8.6, J9.6, J10.6, J11.6, J12.6, J13.6, J14.6, J15.6, J16.6, U1.32 (PD2(INT0))
GND: C2.2, C3.2, C5.2, C6.2, C7.2, C10.-, C11.2, C13.2, C14.2, C15.2, C16.2, C17.2, C18.-, C19.-, D1.A, J1.6, J2.8, J3.8, J4.8, J5.8, J6.8, J7.8, J8.8, J9.8, J10.8, J11.8, J12.8, J13.8, J14.8, J15.8, J16.8, J17.P1_6 (GND), J17.P1_9 (GND), J17.P1_14 (GND), J17.P1_20 (GND), J17.P1_25 (GND), J18.8, J19.8, J20.GND (-), J22.1, J22.3, Q1.2 (S), Q2.2 (S), Q3.2 (S), R5.1, TP1.P$1, U1.3 (GND), U1.5 (AGND), U1.21 (GND), U3.4 (GND), U4.3 (GND)
GREEN: J17.P1_22 (GPIO25), Q1.1 (G)
unnamed: U3.2 (X2), Y1.1
unnamed: R4.1, R5.2, U4.4 (FB)
unnamed: R6.2, U4.5 (COMP)
unnamed: C2.1, U1.20 (AREF)
unnamed: C16.1, C17.1, C18.+, C19.+, F1.1, L1.P$2 (2), R4.2
unnamed: U3.1 (X1), Y1.2
unnamed: C12.1, U4.2 (BS)
unnamed: C13.1, U4.8 (VBIAS)
unnamed: LED1.4 (GREEN_C), R1.1
unnamed: Q1.3 (D), R1.2
unnamed: Q2.3 (D), R2.2
unnamed: LED1.5 (RED_C), R2.1
unnamed: LED1.6 (BLUE_C), R3.1
unnamed: Q3.3 (D), R3.2
unnamed: C14.1, R6.1
unnamed: C12.2, D1.C, L1.P$1 (1), U4.1 (LX)
RED: J17.P1_18 (GPIO24), Q2.1 (G)
RPI_MISO: J17.P1_21 (GPIO9_MISO), J18.4, J19.4
RPI_MOSI: J17.P1_19 (GPIO10_MOSI), J18.5, J19.5
RPI_RX: J17.P1_10 (GPIO15,UART0_RXD), U1.12 (PB0(ICP))
RPI_SCL: J17.P1_5 (GPIO3,I2C0_SCL), U1.28 (PC5(ADC5/SCL)), U3.6 (SCL)
RPI_SCLK: J17.P1_23 (GPIO11_SCLK), J18.6, J19.6
RPI_SDA: J17.P1_3 (GPIO2,I2C0_SDA), U1.27 (PC4(ADC4/SDA)), U3.5 (SDA)
RPI_TX: J17.P1_8 (GPIO14,UART0_TXD), U1.13 (PB1(OC1A))
RX1: J2.5, U1.1 (PD3(INT1))
RX2: J3.5, U1.9 (PD5(T1))
RX3: J4.5, U1.11 (PD7(AIN1))
RX4/MOSI: J1.4, J5.5, U1.15 (PB3(MOSI/OC2))
RX5/SCK: J1.3, J6.5, U1.17 (PB5(SCK))
RX6: J7.5, U1.8 (PB7(XTAL2/TOSC2))
RX7: J8.5, U1.24 (PC1(ADC1))
RX8: J9.5, U1.30 (PD0(RXD))
RX9: J10.5, U1.2 (PD4(XCK/T0))
RX10: J11.5, U1.10 (PD6(AIN0))
RX11: J12.5, U1.14 (PB2(SS/OC1B))
RX12/MISO: J1.1, J13.5, U1.16 (PB4(MISO))
RX13: J14.5, U1.7 (PB6(XTAL1/TOSC1))
RX14: J15.5, U1.23 (PC0(ADC0))
RX15: J16.5, U1.25 (PC2(ADC2))
SYNC: J2.7, J3.7, J4.7, J5.7, J6.7, J7.7, J8.7, J9.7, J10.7, J11.7, J12.7, J13.7, J14.7, J15.7, J16.7, U1.26 (PC3(ADC3))
TX: J2.4, J3.4, J4.4, J5.4, J6.4, J7.4, J8.4, J9.4, J10.4, J11.4, J12.4, J13.4, J14.4, J15.4, J16.4, U1.31 (PD1(TXD))
VIN: C10.+, C11.1, C15.1, J2.1, J3.1, J4.1, J5.1, J6.1, J7.1, J8.1, J9.1, J10.1, J11.1, J12.1, J13.1, J14.1, J15.1, J16.1, J18.1, J19.1, J22.2, J22.4, U4.6 (EN), U4.7 (VIN)

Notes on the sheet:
Programming Header
RTC
Accessory Port 1
I2C Pullups on RPI 1.8k to 3.3V
Accessory Port 2
Pump1
Pump2
Pump9
Pump8
Pump10
Pump11
Pump3
Pump4
Pump12
Pump5
Pump13
Pump6
Pump14
Pump7
Pump15
Rev 1 to Rev 1.1 Changes: Swapped PD0 and PD1
Party Robotics (pmichael)
5V 3A Out
Power In
24V 3A
RPI Header

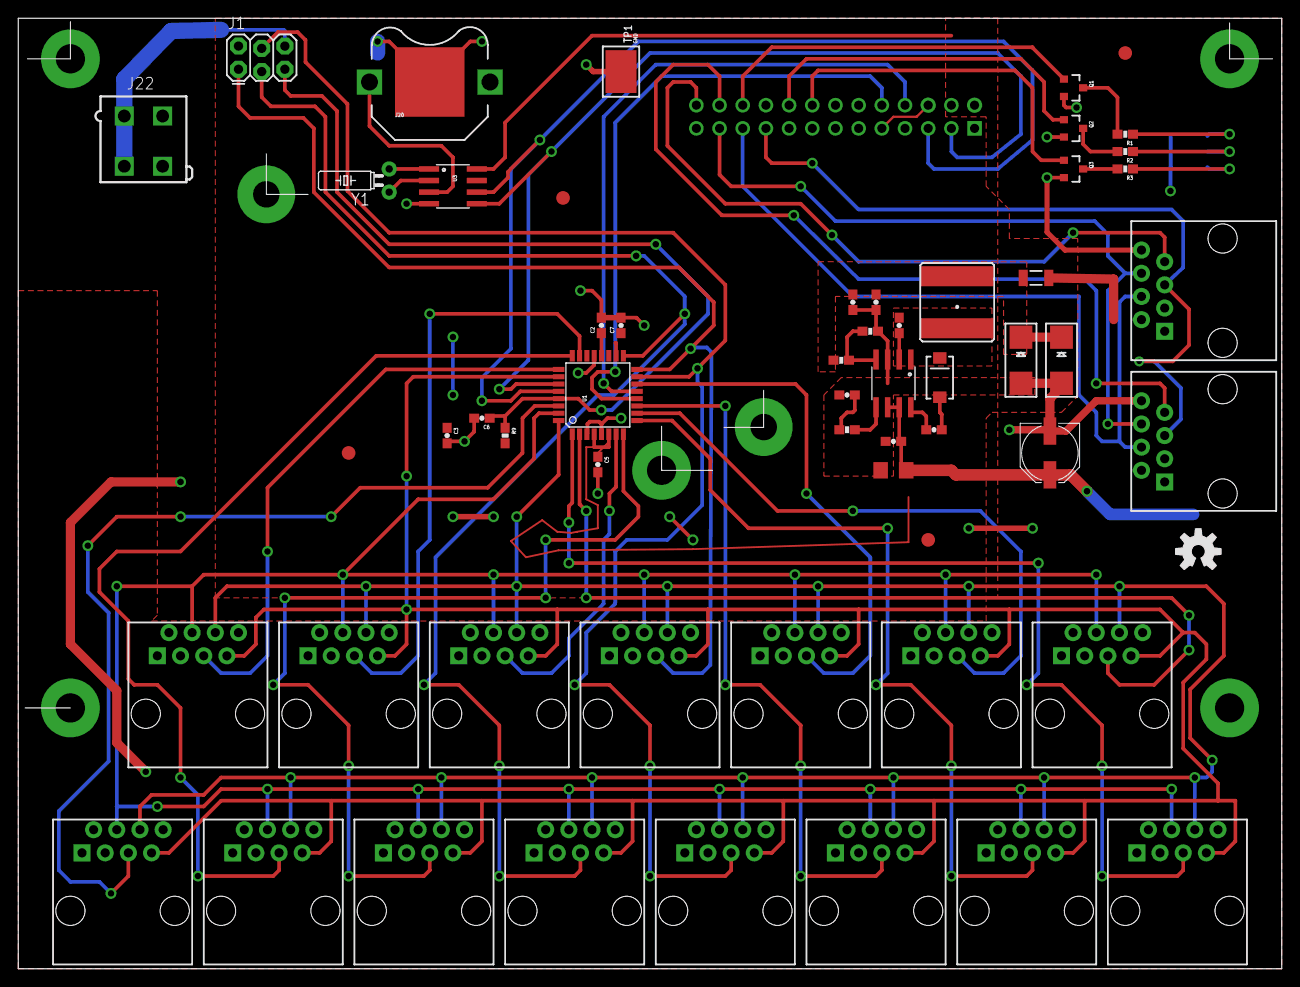
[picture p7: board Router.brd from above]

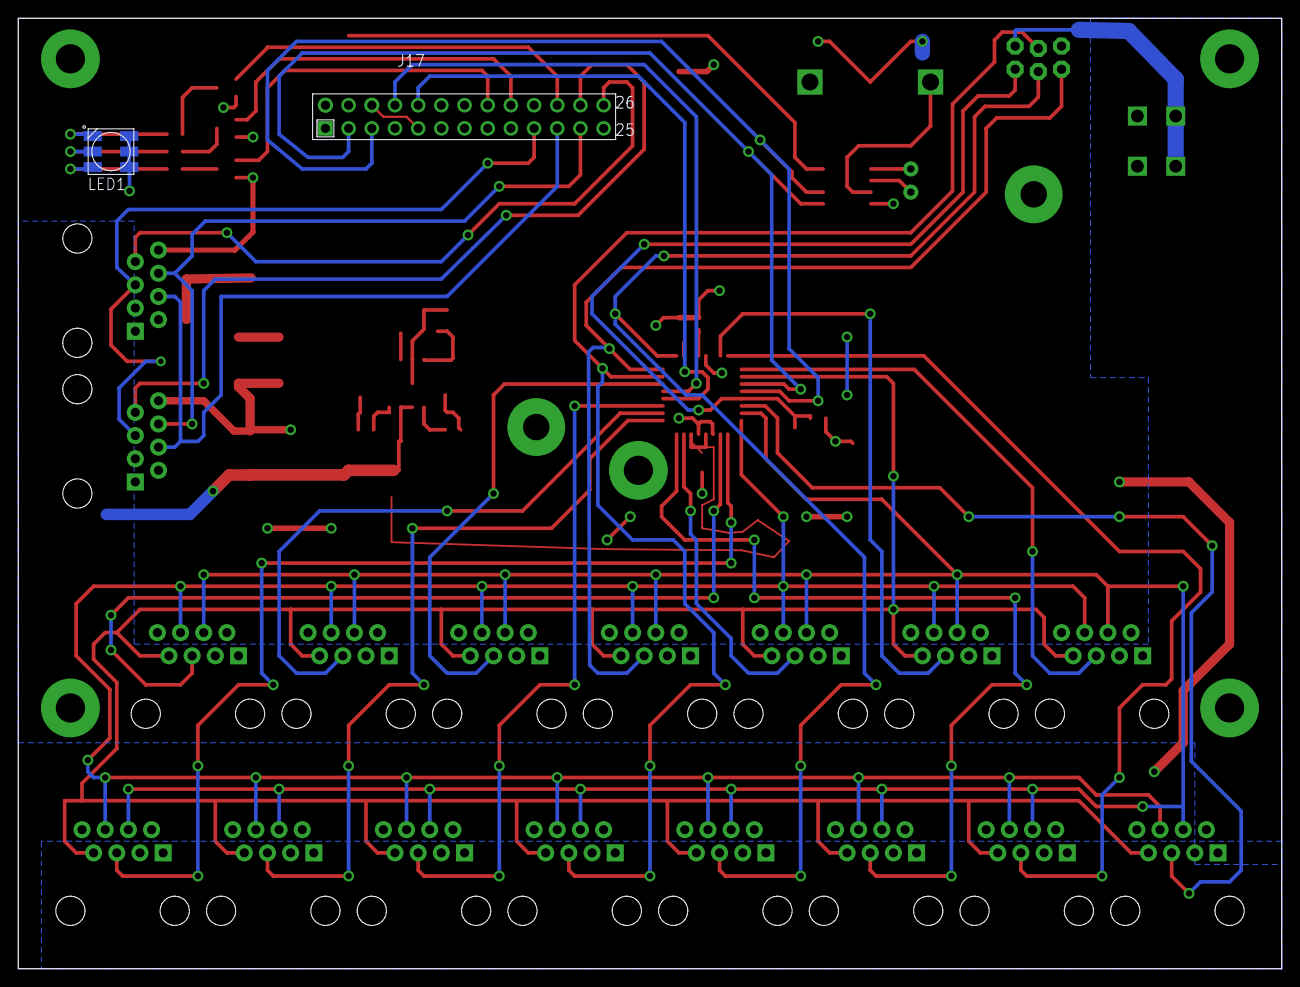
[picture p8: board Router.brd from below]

Board: 2 copper layers, 138.4 x 104.1 mm, 61 parts (2 on the bottom side), 52 nets.

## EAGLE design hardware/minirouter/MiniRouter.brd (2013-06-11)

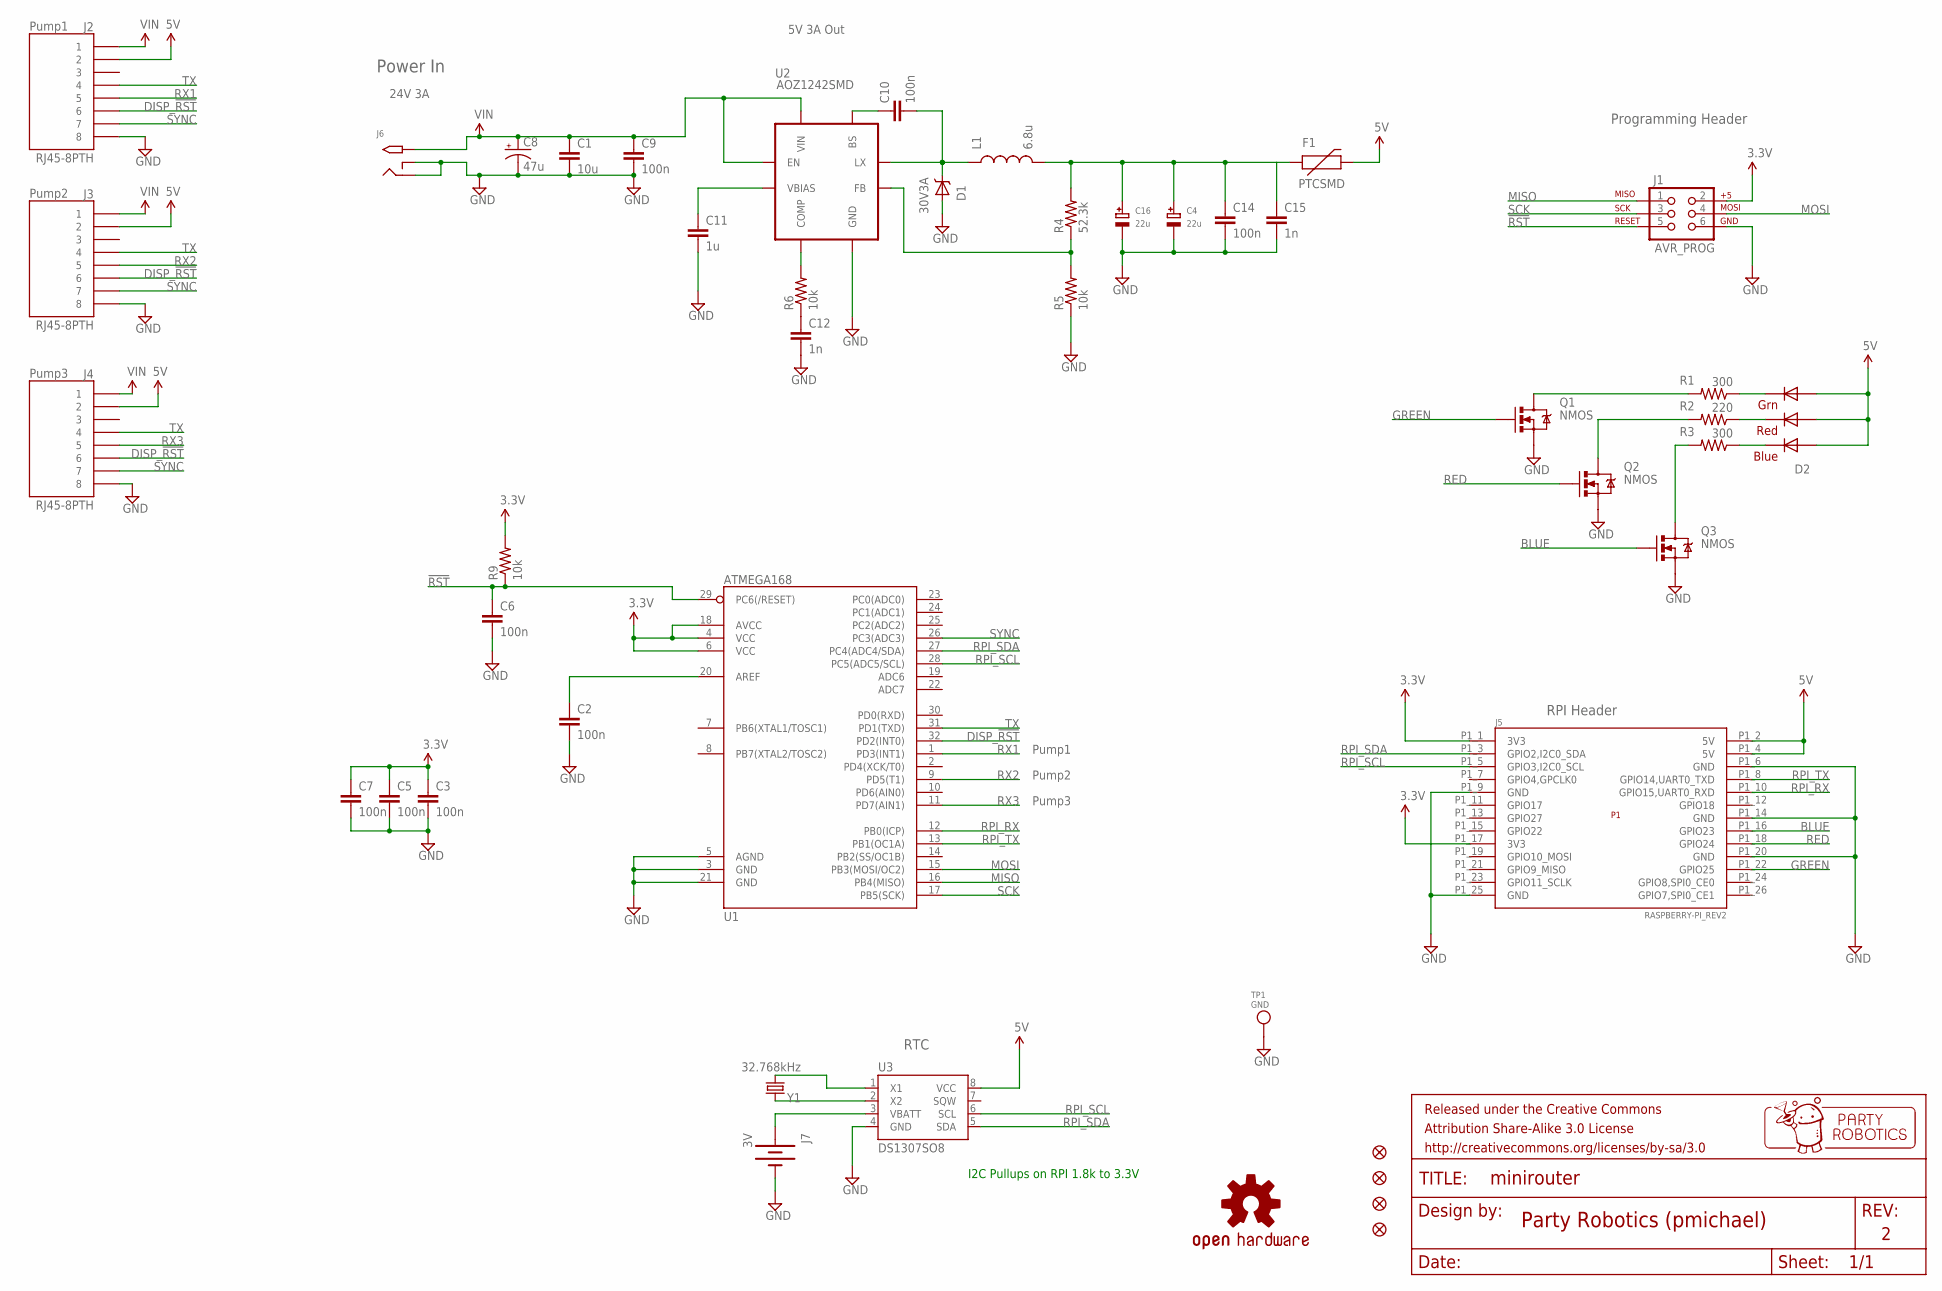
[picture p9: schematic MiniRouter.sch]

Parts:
C1: 10u; 1206
C2, C3, C5, C6, C7, C9, C10, C14: 100n; 0603-CAP
C4, C16: 22u; EIA6032-28/C-R
C8: 47u; PANASONIC_D
C11: 1u; 0603-CAP
C12, C15: 1n; 0603-CAP
D1: 30V3A; SMA-DIODE
D2: RGBLED5050
F1: PTCSMD; PTC-1206
FRAME3: FRAME-LETTER; CREATIVE_COMMONS
J1: AVR_PROG; 2X3_LOCK
J2, J3, J4: RJ45-8PTH; RJ45-8
J5: RASPBERRY-PI_REV2
J6: 2.1MMJACKTHM; PJ-102A
J7: 3V; BATTCON_12MM_PTH
JP1, JP2, JP3, JP4: FIDUCIAL1.5X3; FIDUCIAL-1.5X3
L1: 6.8u; IND_8X8X4
Q1, Q2, Q3: NMOS; SOT23-3
R1, R3: 300; 0603-RES
R2: 220; 0603-RES
R4: 52.3k; 0603-RES
R5, R6, R9: 10k; 0603-RES
TP1: GND; TESTPOINT_SMT
U1: ATMEGA168; TQFP32-08
U2: AOZ1242SMD; SO08
U3: DS1307SO8; SO08
U$46: OSHW-LOGOM; OSHW-LOGO-M
Y1: 32.768kHz; TC26HEZ

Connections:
3.3V: C3.1, C5.1, C7.1, J1.2, J5.P1_1 (3V3), J5.P1_17 (3V3), R9.2, U1.4 (VCC), U1.6 (VCC), U1.18 (AVCC)
5V: D2.1 (BLUE_A), D2.2 (RED_A), D2.3 (GREEN_A), F1.2, J2.2, J3.2, J4.2, J5.P1_2 (5V), J5.P1_4 (5V), U3.8 (VCC)
!RST: C6.1, J1.5, R9.1, U1.29 (PC6(/RESET))
BAT1+: J7.VCC@1 (+), U3.3 (VBATT)
BLUE: J5.P1_16 (GPIO23), Q3.1 (G)
DISP_!RST: J2.6, J3.6, J4.6, U1.32 (PD2(INT0))
GND: C1.2, C2.2, C3.2, C4.-, C5.2, C6.2, C7.2, C8.-, C9.2, C11.2, C12.2, C14.2, C15.2, C16.-, D1.A, J1.6, J2.8, J3.8, J4.8, J5.P1_6 (GND), J5.P1_9 (GND), J5.P1_14 (GND), J5.P1_20 (GND), J5.P1_25 (GND), J6.RING, J6.RING_SW, J7.GND (-), Q1.2 (S), Q2.2 (S), Q3.2 (S), R5.1, TP1.P$1, U1.3 (GND), U1.5 (AGND), U1.21 (GND), U2.3 (GND), U3.4 (GND)
GREEN: J5.P1_22 (GPIO25), Q1.1 (G)
MISO: J1.1, U1.16 (PB4(MISO))
MOSI: J1.4, U1.15 (PB3(MOSI/OC2))
unnamed: U3.2 (X2), Y1.1
unnamed: R4.1, R5.2, U2.4 (FB)
unnamed: R6.2, U2.5 (COMP)
unnamed: C2.1, U1.20 (AREF)
unnamed: C4.+, C14.1, C15.1, C16.+, F1.1, L1.P$2 (2), R4.2
unnamed: U3.1 (X1), Y1.2
unnamed: C10.1, U2.2 (BS)
unnamed: C11.1, U2.8 (VBIAS)
unnamed: D2.4 (GREEN_C), R1.1
unnamed: Q1.3 (D), R1.2
unnamed: Q2.3 (D), R2.2
unnamed: D2.5 (RED_C), R2.1
unnamed: D2.6 (BLUE_C), R3.1
unnamed: Q3.3 (D), R3.2
unnamed: C12.1, R6.1
unnamed: C10.2, D1.C, L1.P$1 (1), U2.1 (LX)
RED: J5.P1_18 (GPIO24), Q2.1 (G)
RPI_RX: J5.P1_10 (GPIO15,UART0_RXD), U1.12 (PB0(ICP))
RPI_SCL: J5.P1_5 (GPIO3,I2C0_SCL), U1.28 (PC5(ADC5/SCL)), U3.6 (SCL)
RPI_SDA: J5.P1_3 (GPIO2,I2C0_SDA), U1.27 (PC4(ADC4/SDA)), U3.5 (SDA)
RPI_TX: J5.P1_8 (GPIO14,UART0_TXD), U1.13 (PB1(OC1A))
RX1: J2.5, U1.1 (PD3(INT1))
RX2: J3.5, U1.9 (PD5(T1))
RX3: J4.5, U1.11 (PD7(AIN1))
SCK: J1.3, U1.17 (PB5(SCK))
SYNC: J2.7, J3.7, J4.7, U1.26 (PC3(ADC3))
TX: J2.4, J3.4, J4.4, U1.31 (PD1(TXD))
VIN: C1.1, C8.+, C9.1, J2.1, J3.1, J4.1, J6.TIP, U2.6 (EN), U2.7 (VIN)

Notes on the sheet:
Programming Header
RPI Header
RTC
5V 3A Out
Power In
I2C Pullups on RPI 1.8k to 3.3V
Pump2
Pump3
Pump1
Party Robotics (pmichael)
24V 3A

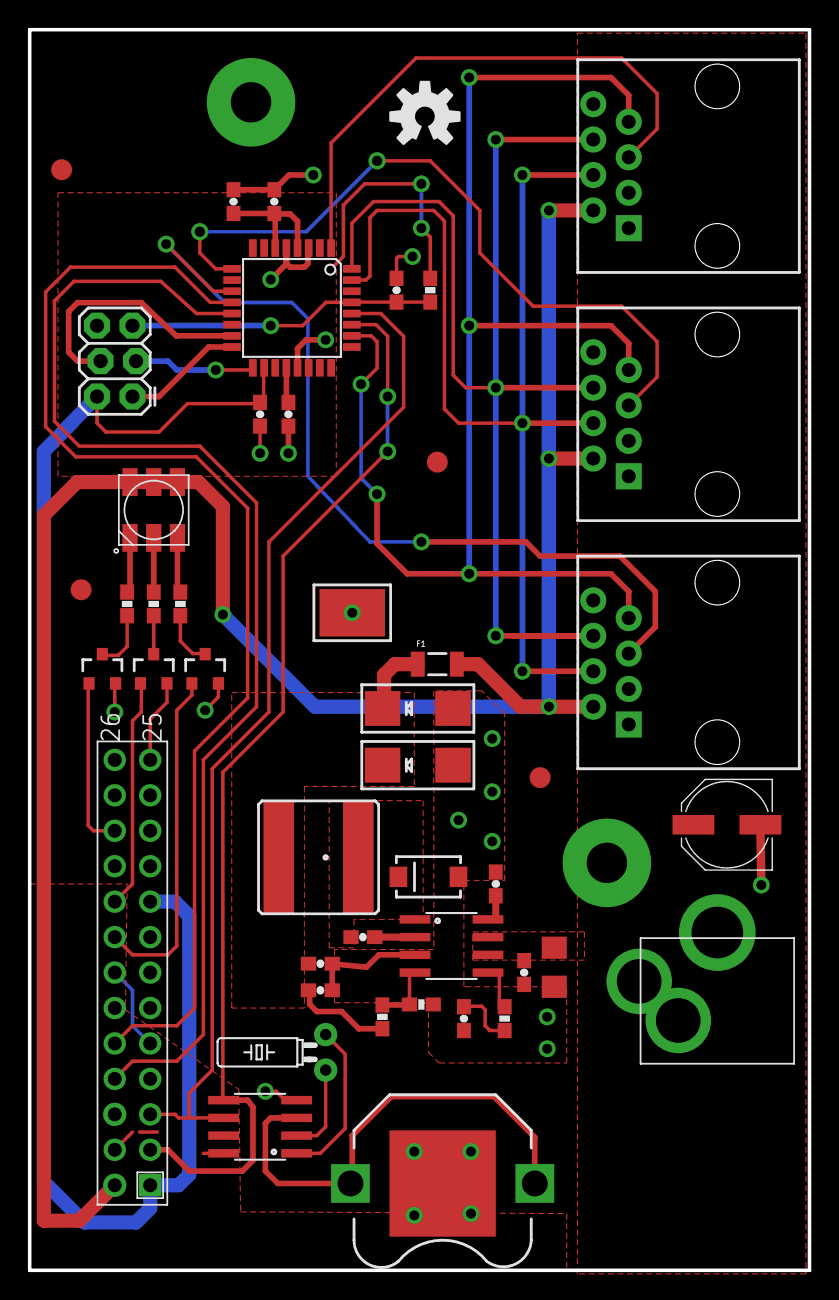
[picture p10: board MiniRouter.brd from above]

Board: 2 copper layers, 55.9 x 88.9 mm, 47 parts (0 on the bottom side), 38 nets.

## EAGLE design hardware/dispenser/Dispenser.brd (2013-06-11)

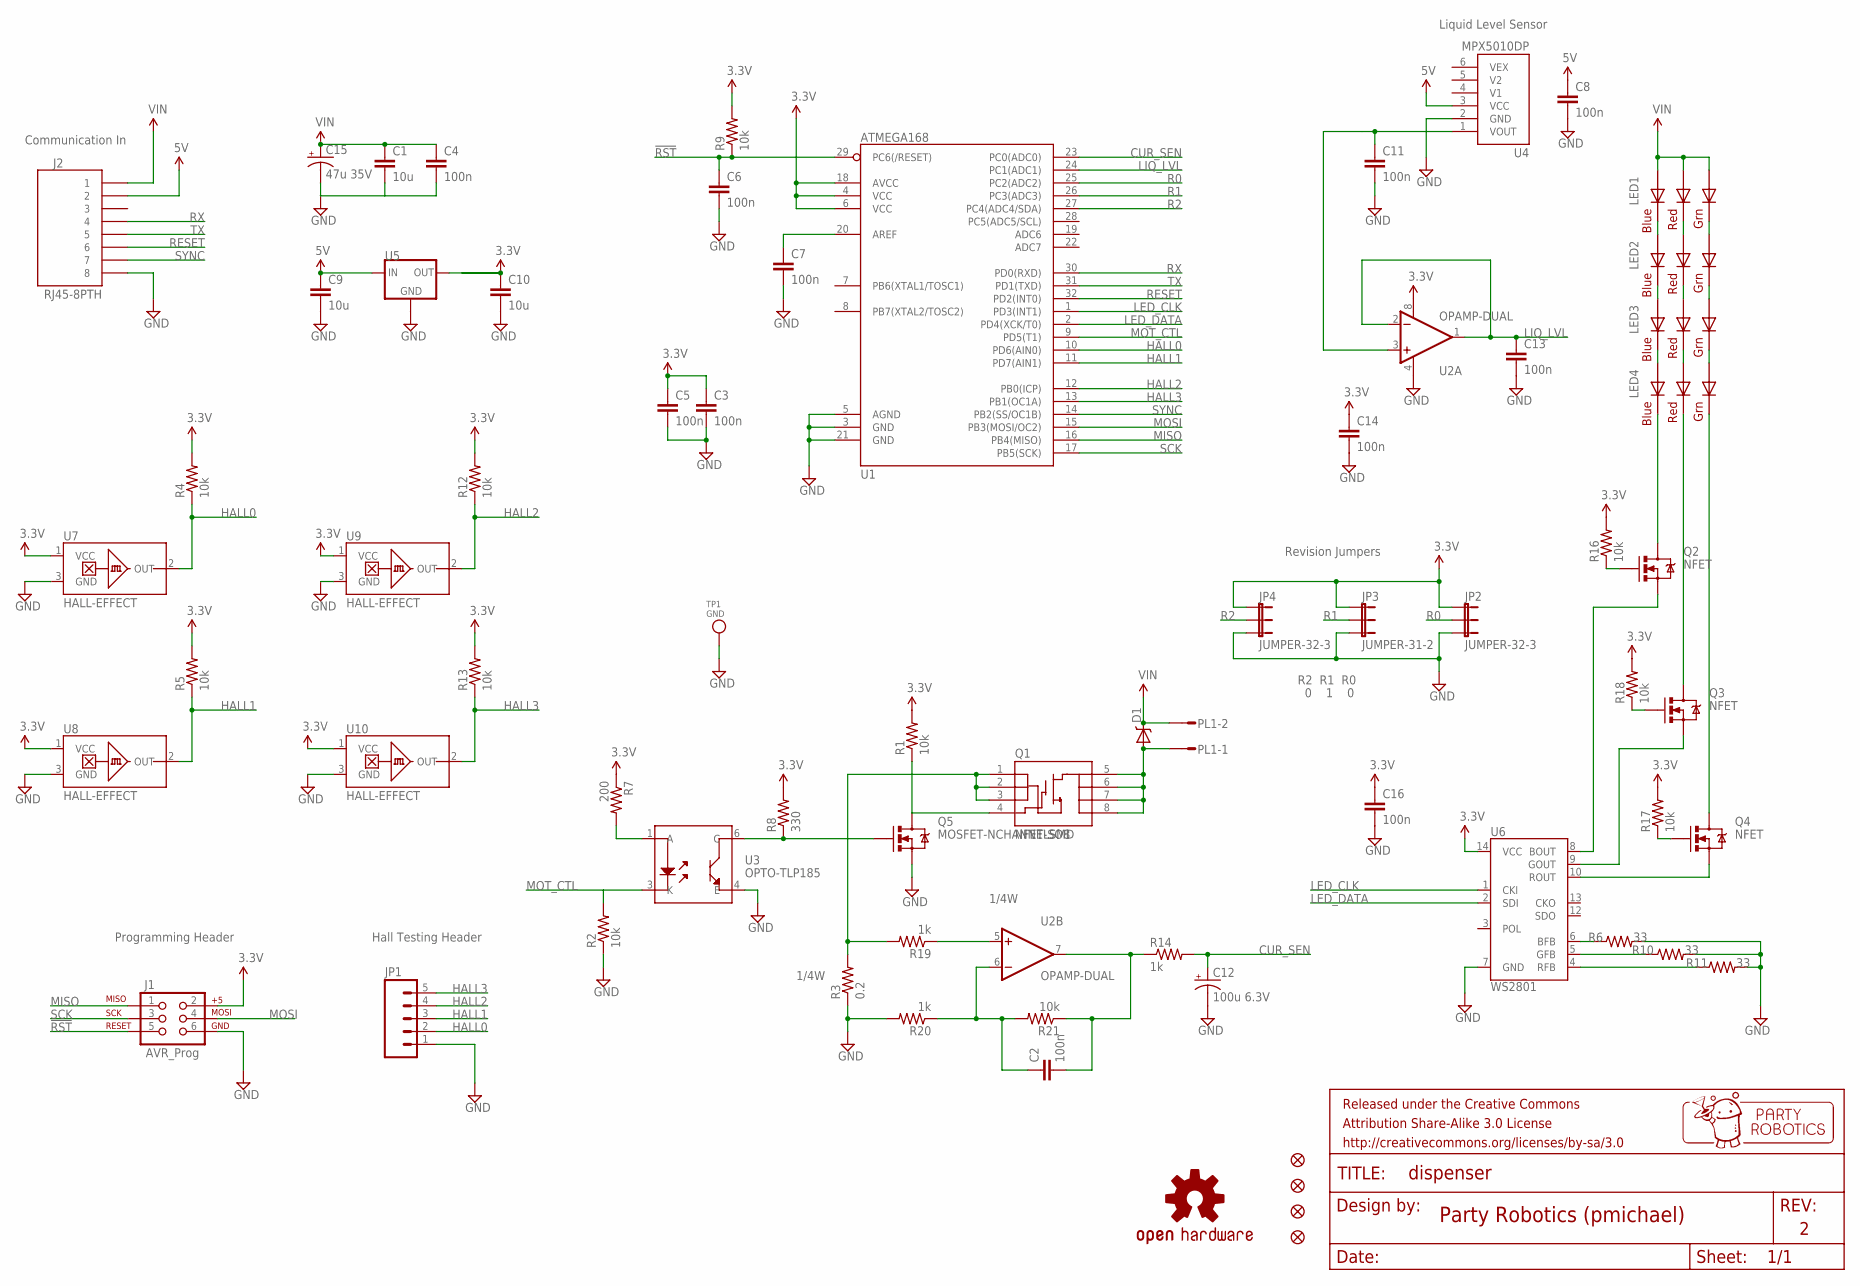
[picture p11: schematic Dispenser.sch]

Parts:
C1, C9, C10: 10u; 0603-CAP
C2, C3, C4, C5, C6, C7, C8, C11, C13, C14, C16: 100n; 0603-CAP
C12: 100u 6.3V; PANASONIC_D
C15: 47u 35V; PANASONIC_D
D1: B330A; SMA-DIODE
FRAME3: FRAME-LETTER; CREATIVE_COMMONS
J1: AVR_Prog; 2X3_LOCK
J2: RJ45-8PTH; RJ45-8
JP1: M051.27MM; 1X05-1.27MM
JP2, JP4: JUMPER-32-3; SJ_3_PASTE2&3
JP3: JUMPER-31-2; SJ_3_PASTE1&2
JP5, JP6, JP7, JP8: FIDUCIAL1X2; FIDUCIAL-1X2
LED1, LED2, LED3, LED4: RGBLED5050
PL1: DF3-02P; DF3P-02
Q1: NFET-SO8; SO08
Q2, Q3, Q4: NFET; SOT23-3
Q5: MOSFET-NCHANNELSMD; SOT23-3
R1, R2, R4, R5, R9, R12, R13, R16, R17, R18, R21: 10k; 0603-RES
R3: 0.2; 0805
R6, R10, R11: 33; 0603-RES
R7: 200; 0603-RES
R8: 330; 0603-RES
R14, R19, R20: 1k; 0603-RES
TP1: GND; TESTPOINT_SMT
U1: ATMEGA168; TQFP32-08
U2: OPAMP-DUAL; SO08
U3: OPTO-TLP185; SO6
U4: MPX5010DP
U5: VREG-5V-LDO-AP1117SOT89-3L; SOT89-3L
U6: WS2801; SOP-14
U7, U8, U9, U10: HALL-EFFECT; SOT23-3
U$1: OSHW-LOGOM; OSHW-LOGO-M

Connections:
1/4W: Q1.1 (S), Q1.2 (S), Q1.3 (S), R3.2, R19.2
3.3V: C3.1, C5.1, C8.1, C10.1, C14.1, C16.1, J1.2, JP2.1, JP3.1, JP4.1, R1.2, R4.2, R5.2, R7.1, R8.2, R9.2, R12.2, R13.2, R16.2, R17.2, R18.2, U1.4 (VCC), U1.6 (VCC), U1.18 (AVCC), U2.8 (V+), U5.2 (OUT), U5.2.1 (OUT), U6.14 (VCC), U7.1 (VCC), U8.1 (VCC), U9.1 (VCC), U10.1 (VCC)
5V: C9.1, J2.2, U4.3 (VCC), U5.3 (IN)
!RST: C6.1, J1.5, R9.1, U1.29 (PC6(/RESET))
BLUE: Q2.2 (S), U6.8 (BOUT)
CUR_SEN: C12.+, R14.2, U1.23 (PC0(ADC0))
GND: C1.2, C3.2, C4.2, C5.2, C6.2, C7.2, C8.2, C9.2, C10.2, C11.2, C12.-, C13.2, C14.2, C15.-, C16.2, J1.6, J2.8, JP1.1, JP2.3, JP3.3, JP4.3, Q5.2 (S), R2.1, R3.1, R6.2, R10.2, R11.2, R20.2, TP1.P$1, U1.3 (GND), U1.5 (AGND), U1.21 (GND), U2.4 (V-), U3.4 (E), U4.2 (GND), U5.1 (GND), U6.7 (GND), U7.3 (GND), U8.3 (GND), U9.3 (GND), U10.3 (GND)
GREEN: Q3.2 (S), U6.9 (GOUT)
HALL0: JP1.2, R4.1, U1.10 (PD6(AIN0)), U7.2 (OUT)
HALL1: JP1.3, R5.1, U1.11 (PD7(AIN1)), U8.2 (OUT)
HALL2: JP1.4, R12.1, U1.12 (PB0(ICP)), U9.2 (OUT)
HALL3: JP1.5, R13.1, U1.13 (PB1(OC1A)), U10.2 (OUT)
LED_CLK: U1.1 (PD3(INT1)), U6.1 (CKI)
LED_DATA: U1.2 (PD4(XCK/T0)), U6.2 (SDI)
LIQ_LVL: C13.1, U1.24 (PC1(ADC1)), U2.1 (OUT), U2.2 (-IN)
MISO: J1.1, U1.16 (PB4(MISO))
MOSI: J1.4, U1.15 (PB3(MOSI/OC2))
MOT_B: D1.A, PL1.1, Q1.5 (D), Q1.6 (D), Q1.7 (D), Q1.8 (D)
MOT_CTL: R2.2, U1.9 (PD5(T1)), U3.3 (K)
MOT_CUR: C2.2, R14.1, R21.1, U2.7 (OUT)
unnamed: C7.1, U1.20 (AREF)
unnamed: Q3.1 (G), R18.1
unnamed: Q4.1 (G), R17.1
unnamed: Q2.1 (G), R16.1
unnamed: R6.1, U6.6 (BFB)
unnamed: R10.1, U6.5 (GFB)
unnamed: R11.1, U6.4 (RFB)
unnamed: Q1.4 (G), Q5.3 (D), R1.1
unnamed: C2.1, R20.1, R21.2, U2.6 (-IN)
unnamed: R19.1, U2.5 (+IN)
unnamed: LED4.6 (BLUE_C), Q2.3 (D)
unnamed: LED4.5 (RED_C), Q3.3 (D)
unnamed: LED4.4 (GREEN_C), Q4.3 (D)
unnamed: R7.2, U3.1 (A)
unnamed: Q4.2 (S), U6.10 (ROUT)
unnamed: C11.1, U2.3 (+IN), U4.1 (VOUT)
unnamed: LED3.6 (BLUE_C), LED4.1 (BLUE_A)
unnamed: Q5.1 (G), R8.1, U3.6 (C)
unnamed: LED3.5 (RED_C), LED4.2 (RED_A)
unnamed: LED3.4 (GREEN_C), LED4.3 (GREEN_A)
unnamed: LED2.4 (GREEN_C), LED3.3 (GREEN_A)
unnamed: LED2.5 (RED_C), LED3.2 (RED_A)
unnamed: LED2.6 (BLUE_C), LED3.1 (BLUE_A)
unnamed: LED1.4 (GREEN_C), LED2.3 (GREEN_A)
unnamed: LED1.5 (RED_C), LED2.2 (RED_A)
unnamed: LED1.6 (BLUE_C), LED2.1 (BLUE_A)
R0: JP2.2, U1.25 (PC2(ADC2))
R1: JP3.2, U1.26 (PC3(ADC3))
R2: JP4.2, U1.27 (PC4(ADC4/SDA))
RESET: J2.6, U1.32 (PD2(INT0))
RX: J2.4, U1.30 (PD0(RXD))
SCK: J1.3, U1.17 (PB5(SCK))
SYNC: J2.7, U1.14 (PB2(SS/OC1B))
TX: J2.5, U1.31 (PD1(TXD))
VIN: C1.1, C4.1, C15.+, D1.C, J2.1, LED1.1 (BLUE_A), LED1.2 (RED_A), LED1.3 (GREEN_A), PL1.2

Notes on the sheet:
Programming Header
Liquid Level Sensor
Party Robotics (pmichael)
Hall Testing Header
Communication In
Revision Jumpers
R2 R1 R0
0 1 0

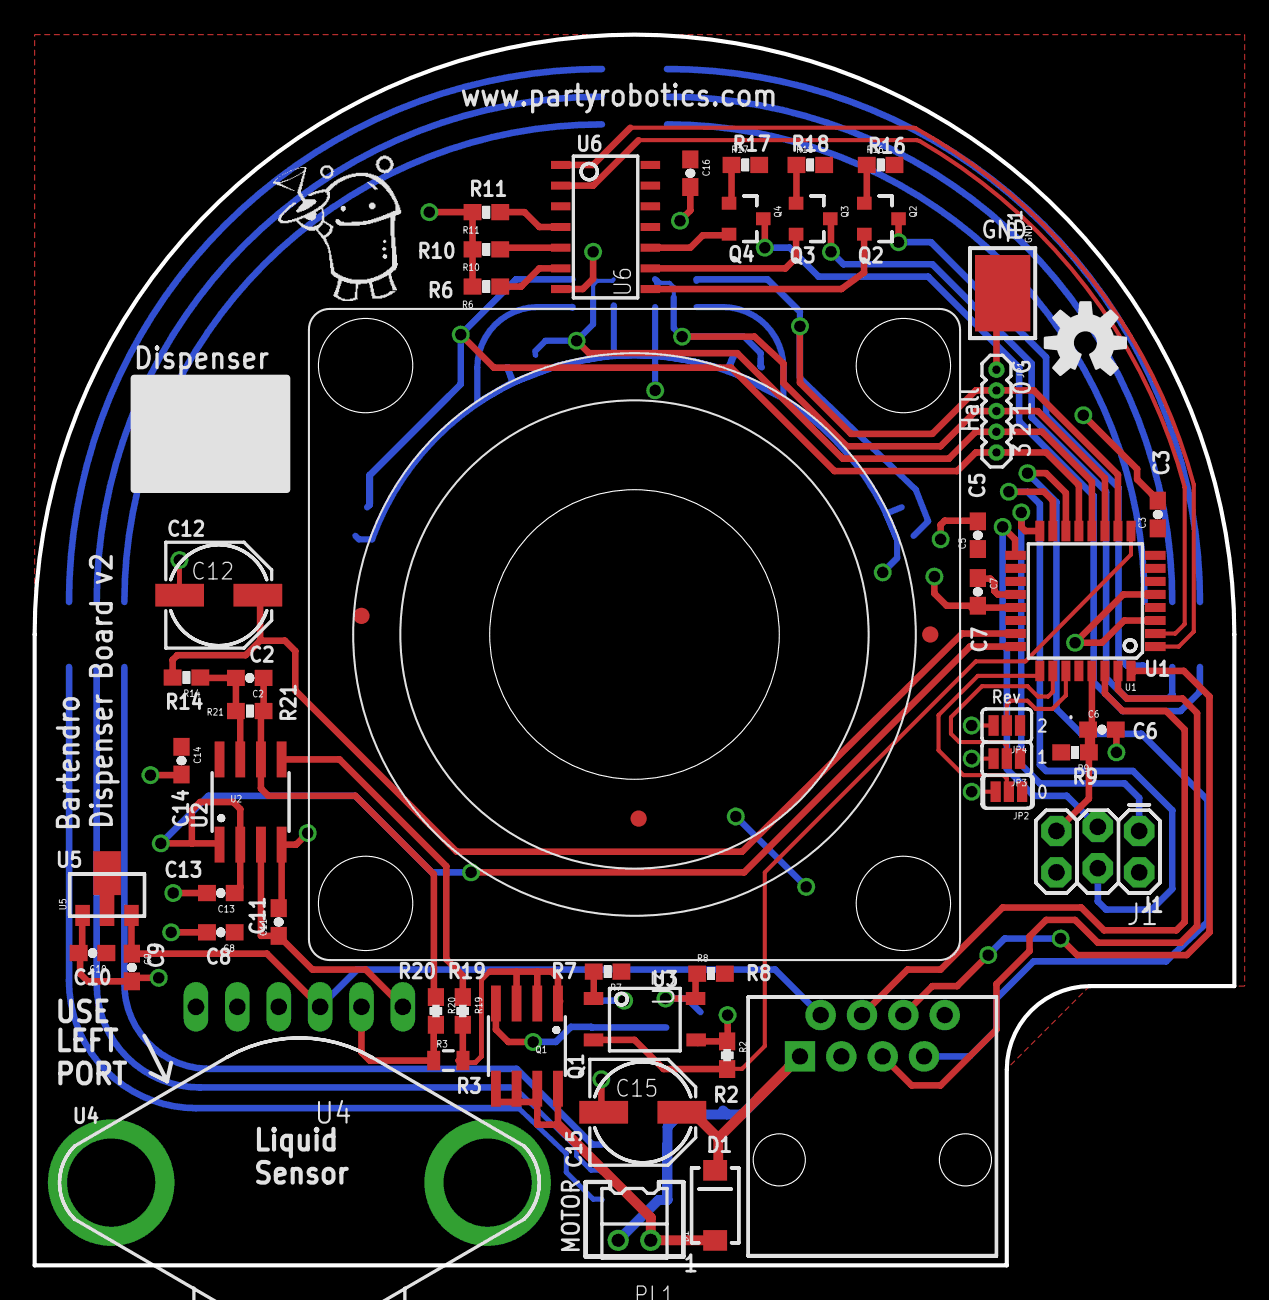
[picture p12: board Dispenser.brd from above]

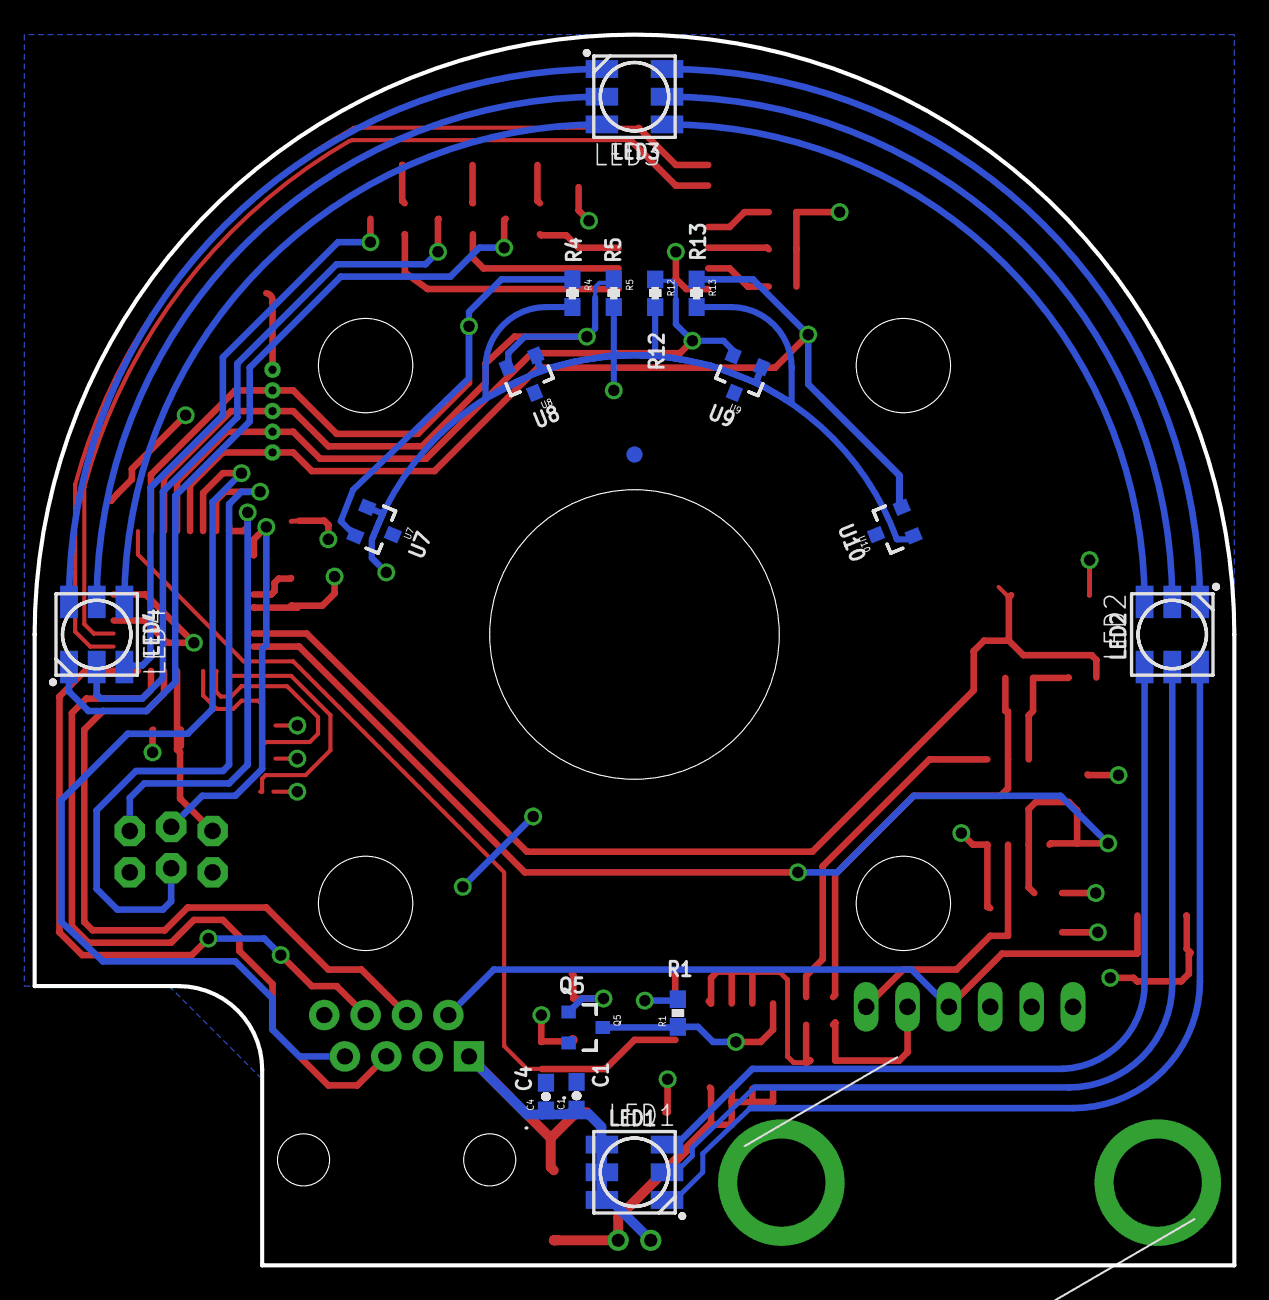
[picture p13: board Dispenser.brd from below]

Board: 2 copper layers, 73.7 x 75.6 mm, 70 parts (17 on the bottom side), 55 nets.

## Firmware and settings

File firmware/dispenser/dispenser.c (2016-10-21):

#include <avr/io.h>
#include <avr/interrupt.h>
#include <util/delay.h>

#include <stddef.h>
#include <math.h>
#include <stdio.h>
#include <stdlib.h>
#include <string.h>
#include <avr/eeprom.h>
#include <stdarg.h>
#include <stdlib.h>
#include "defs.h"

#include "packet.h"
#include "serial.h"
#include "led.h"

// EEprom data. 
#define ee_pump_id_offset                 0
#define ee_run_time_ticks_offset          1
#define ee_liquid_low_threshold_offset    5
#define ee_liquid_out_threshold_offset    7 

#define SOFTWARE_VERSION                  4

#define USER_BUTTON_DURATION             10 // in clock ticks
#define RESET_DURATION                    1
#define SYNC_COUNT                       10 // Every SYNC_INIT ms we will change the color animation
#define NUM_ADC_SAMPLES                   5
#define TICKS_SAVE_THRESHOLD           1000
#define DEFAULT_LIQUID_LOW_THRESHOLD    140
#define DEFAULT_LIQUID_OUT_THRESHOLD     90
#define DEFAULT_CURRENT_SENSE_THRESHOLD 610
#define MOTOR_DIRECTION_FORWARD           1
#define MOTOR_DIRECTION_BACKWARD          0

// this (non volatile) variable keeps the current liquid level
static uint16_t g_liquid_level = 0;

volatile uint32_t g_time = 0;
static volatile uint32_t g_reset_fe_time = 0;
static volatile uint32_t g_reset = 0;
static volatile uint32_t g_ticks = 0;
static volatile uint32_t g_dispense_target_ticks = 0;
static volatile uint8_t g_is_dispensing = 0;
static volatile uint8_t g_is_motor_on = 0;
static volatile uint8_t g_motor_direction = MOTOR_DIRECTION_FORWARD;
static volatile uint32_t g_button_time = 0;
static volatile uint8_t g_button_state = 0;

static volatile uint8_t g_hall0 = 0;
static volatile uint8_t g_hall1 = 0;
static volatile uint8_t g_hall2 = 0;
static volatile uint8_t g_hall3 = 0;
static volatile uint8_t g_sync = 0;
static volatile uint32_t g_sync_count = 0, g_pattern_t = 0;
static volatile uint8_t g_sync_divisor = 10;

static volatile uint8_t g_current_sense_detected = 0;
static volatile uint8_t g_current_sense_state = 0;
static volatile uint8_t g_current_sense_enabled = 1;

void check_dispense_complete_isr(void);
void set_motor_speed(uint8_t speed, uint8_t use_current_sense);
void set_motor_direction(uint8_t direction);
void stop_motor(void);
void pulse_motor_driver_retry(void);
void adc_shutdown(void);
uint8_t check_reset(void);
void is_dispensing(void);
void flush_saved_tick_count(uint8_t force);
void set_led_pattern(uint8_t pattern);

/*
   0  - PD0 - RX
   1  - PD1 - TX
   2  - PD2 - RESET
   3  - PD3 - LED clock
   4  - PD4 - LED data
   5  - PD5 - motor control B (OC0B)
   6  - PD6 - motor control A (OC0A)
   7  - PD7 - Hall 0 (pcint 23)
   8  - PB0 - Hall 1 (pcint 0)
   9  - PB1 - Hall 2 (pcint 1) 
  10  - PB2 - Hall 3 (pcint 2)
  14  - PB6 - /RTRY for motor driver
  15  - PB7 - BUTTON (pcint7)
  A0  - PC0 - Current Sense (since v3 a digital function) (pcint 8)
  A1  - PC1 - liquid level
  A2  - PC2 - REV0
  A3  - PC3 - REV1
  A4  - PC4 - REV2
  A5  - PC5 - SYNC (pcint13)

*/
void setup(void)
{
    serial_init();

    // Set up LEDs & motor control outputs
    DDRD |= (1<<PD3)|(1<<PD4)|(1<<PD5)|(1<<PD6);
    DDRB |= (1<<PB6);

    // pull ups for hall sensors & for current sense
    sbi(PORTD, 7);
    sbi(PORTB, 0);
    sbi(PORTB, 1);
    sbi(PORTB, 2);
    sbi(PORTC, 0);

    // Timer setup for reset pulse width measuring
    TCCR1B |= TIMER1_FLAGS;
    TCNT1 = TIMER1_INIT;
    TIMSK1 |= (1<<TOIE1);

    // Set to Phase correct PWM, compare output mode
    TCCR0A |= _BV(WGM00) | _BV(COM0A1) | _BV(COM0B1);

    // Set the clock source
    TCCR0B |= (0 << CS00) | (1 << CS01);

    // Reset timers and comparators
    OCR0A = 0;
    OCR0B = 0;
    TCNT0 = 0;

    // INT0 for router reset
    EICRA |= (1 << ISC00);
    EIMSK |= (1 << INT0);

    // PCINT setup
    PCMSK0 |= (1 << PCINT0) | (1 << PCINT1) | (1 << PCINT2) | (1 << PCINT7);;
    PCMSK1 |= (1 << PCINT8) | (1 << PCINT13);
    PCMSK2 |= (1 << PCINT23);
    PCICR |=  (1 << PCIE2) | (1 << PCIE1) | (1 << PCIE0);

    // Set the motor driver RTRY line HIGH
    sbi(PORTB, 6);
}

// update g_time
ISR (TIMER1_OVF_vect)
{
    g_time++;
    TCNT1 = TIMER1_INIT;
}

// reset pin change
ISR(INT0_vect)
{
    if (PIND & (1<<PIND2))
    {
        g_reset_fe_time = g_time + RESET_DURATION;
    }
    else
    {
        if (g_reset_fe_time > 0 && g_time >= g_reset_fe_time)
            g_reset = 1;
        g_reset_fe_time = 0;
    }
}

ISR(PCINT0_vect)
{
    uint8_t      state;

    state = PINB & (1<<PINB0);
    if (state != g_hall1)
    {
        g_hall1 = state;
        g_ticks++;
    }

    state = PINB & (1<<PINB1);
    if (state != g_hall2)
    {
        g_hall2 = state;
        g_ticks++;
    }
    state = PINB & (1<<PINB2);
    if (state != g_hall3)
    {
        g_hall3 = state;
        g_ticks++;
    }
    state = (PINB & (1<<PINB7)) ? 0 : 1;
    if (state != g_button_state)
    {
        if (!g_button_time)
        {
            g_button_time = g_time + USER_BUTTON_DURATION;
            g_button_state = state;
        }
    }
    check_dispense_complete_isr();
}

ISR(PCINT1_vect)
{
    uint8_t      state;

    state = PINC & (1<<PINC0);
    if (state != g_current_sense_state)
    {
        g_current_sense_state = state;

        if (!state && g_current_sense_enabled)
        {
            stop_motor();
            g_is_dispensing = 0;
            g_dispense_target_ticks = 0;
            set_led_pattern(LED_PATTERN_CURRENT_SENSE);
            g_current_sense_detected = 1;
        }
    }
    state = PINC & (1<<PINC5);
    if (state != g_sync)
    {
        g_sync_count++;
        g_sync = state;
    }
    check_dispense_complete_isr();
}

ISR(PCINT2_vect)
{
    uint8_t state;

    state = PIND & (1<<PIND7);
    if (state != g_hall0)
    {
        g_hall0 = state;
        g_ticks++;
    }

    check_dispense_complete_isr();
}

// this function is called from an ISR, so no need to turn off/on interrupts
void check_dispense_complete_isr(void)
{
    if (g_dispense_target_ticks > 0 && g_ticks >= g_dispense_target_ticks)
    {
         g_dispense_target_ticks = 0;
         g_is_dispensing = 0;
         stop_motor();
         adc_shutdown();
    }
}

uint8_t check_reset(void)
{
    uint8_t reset;

    cli();
    reset = g_reset;
    sei();

    return reset;
}

void idle(void)
{
    color_t c;
    uint8_t animate = 0, current_state = 0, button_state_changed = 0;
    uint32_t t = 0;

    cli();
    if (g_sync_count >= g_sync_divisor)
    {
        g_sync_count = 0;
        animate = 1;
    }

    // read button state & check time
    if (g_button_time > 0 && g_time >= g_button_time)
    {
        current_state = g_button_state;
        g_button_time = 0;
        button_state_changed = 1;
    }
    sei();

    // Set the leds and motor speed accordingly when button is pressed
    if (button_state_changed)
    {
        if (current_state)
            set_motor_speed(255, 1);
        else
            set_motor_speed(0, 1);
    }
      
    // run the animation if the current state 
    if (animate)
    {
        cli();
        t = g_pattern_t++;
        sei();
        // do some animation!
        led_pattern_next(t, &c);
        set_led_rgb(c.red, c.green, c.blue);
    }

    flush_saved_tick_count(0);
}

void flush_saved_tick_count(uint8_t force)
{
    uint8_t is_dispensing;
    uint32_t ticks_to_save;

    cli();
    is_dispensing = g_is_dispensing;
    ticks_to_save = g_ticks;
    sei();

    if (is_dispensing && !force)
        return;

    if (ticks_to_save > TICKS_SAVE_THRESHOLD || (force && ticks_to_save > 0))
    {
        cli();
        g_ticks = 0;
        sei();

        ticks_to_save += eeprom_read_dword((uint32_t *)ee_run_time_ticks_offset);
        eeprom_update_dword((uint32_t *)ee_run_time_ticks_offset, ticks_to_save);
    }
}

void reset_saved_tick_count(void)
{
    uint32_t dispensing;

    // Don't reset the tick count while we're counting!
    cli();
    dispensing = g_is_dispensing;
    sei();
    if (dispensing)
        return;

    cli();
    g_ticks = 0;
    sei();

    eeprom_update_dword((uint32_t *)ee_run_time_ticks_offset, 0);
}

void get_saved_tick_count(void)
{
    uint32_t ticks;

    cli();
    ticks = g_ticks;
    sei();

    send_packet16(PACKET_SAVED_TICK_COUNT, ticks + eeprom_read_dword((uint32_t *)ee_run_time_ticks_offset), 0);
}

void get_liquid_thresholds(void)
{
    uint16_t low, out;

    low = eeprom_read_word((uint16_t *)ee_liquid_low_threshold_offset);
    out = eeprom_read_word((uint16_t *)ee_liquid_out_threshold_offset);

    if (low == 0 || low == 0xFFFF)
        low = DEFAULT_LIQUID_LOW_THRESHOLD; 

    if (out == 0 || out == 0xFFFF)
        out = DEFAULT_LIQUID_OUT_THRESHOLD;

    send_packet16(PACKET_GET_LIQUID_THRESHOLDS, low, out);
}

void set_liquid_thresholds(uint16_t low, uint16_t out)
{
    eeprom_update_word((uint16_t *)ee_liquid_low_threshold_offset, low);
    eeprom_update_word((uint16_t *)ee_liquid_out_threshold_offset, out);
}

void set_led_pattern(uint8_t pattern)
{
    led_pattern_init(pattern);
    cli();
    g_pattern_t = 0;
    sei();
}

void adc_liquid_level_setup(void)
{
    ADCSRA = (1 << ADPS1);
    ADMUX = (1<<REFS0) | (1 << MUX0);
    ADCSRA |= (1<<ADEN);
}

void adc_shutdown(void)
{
    ADCSRA &= ~(1<<ADEN);
}

uint16_t adc_read()
{
    uint8_t hi, low;

    ADCSRA |= (1<<ADSC);
    while(ADCSRA & 0b01000000);
    low = ADCL;
    hi = ADCH;
    return (hi << 8) | low;
}

void update_liquid_level(void)
{
    uint8_t  i;
    uint16_t v = 0;

    adc_liquid_level_setup();
    for(i = 0; i < NUM_ADC_SAMPLES; i++)
        v += adc_read();
    adc_shutdown();

    g_liquid_level = (uint16_t)(v / NUM_ADC_SAMPLES);
}

void get_liquid_level(void)
{
    send_packet16(PACKET_LIQUID_LEVEL, g_liquid_level, 0);
}

void set_motor_direction(uint8_t direction)
{
    if (direction != MOTOR_DIRECTION_FORWARD && direction != MOTOR_DIRECTION_BACKWARD)
        return;

    cli();
    g_motor_direction = direction;
    sei();
}

void set_motor_speed(uint8_t speed, uint8_t use_current_sense)
{
    uint8_t direction;

    cli();
    g_current_sense_enabled = use_current_sense;
    direction = g_motor_direction;
    sei();

    if (direction == MOTOR_DIRECTION_FORWARD)
    {
        OCR0A = speed;
        OCR0B = 0;
    }
    else
    {
        OCR0A = 0;
        OCR0B = speed;
    }

    cli();
    g_is_motor_on = speed != 0;
    sei();
}

void pulse_motor_driver_retry(void)
{
    cbi(PORTB, 6);
    _delay_ms(2);
    sbi(PORTB, 6);
}

void stop_motor(void)
{
    adc_shutdown();
    OCR0A = 0;
    OCR0B = 0;
    cli();
    g_is_motor_on = 0;
    sei();
}

void run_motor_timed(uint16_t duration)
{
    uint16_t t;

    if (duration == 0)
        return;

    set_motor_speed(255, 1);
    for(t = 0; t < duration && !check_reset(); t++)
        _delay_ms(1);
    stop_motor();
}

void dispense_ticks(uint32_t ticks, uint16_t speed)
{
    uint8_t dispensing;

    cli();
    dispensing = g_is_dispensing;
    sei();

    if (dispensing || ticks == 0)
        return;

    cli();
    g_dispense_target_ticks = g_ticks + ticks;
    g_is_dispensing = 1;
    sei();

    set_motor_speed(speed, 1);
}

void is_dispensing(void)
{
    uint8_t dispensing;

    cli();
    dispensing = g_is_dispensing;
    sei();

    send_packet8_2(PACKET_IS_DISPENSING, dispensing, g_current_sense_detected);
}

#define MAX_CMD_LEN 64
// return true is a command was read, false if a reset was requested
uint8_t receive_cmd(char *cmd)
{
    uint8_t num = 0, ch;

    dprint(">");

    *cmd = 0;
    for(; !check_reset();)
    {
        for(;!check_reset() && !serial_rx_nb(&ch);)
            idle();

        if (check_reset())
            return 0;

        serial_tx(ch);
        if (ch == '\r')
        {
            serial_tx('\n');
            cmd[num] = 0;
            return 1;
        }
        cmd[num] = ch;
        num++;
    }
    return 0;
}

void text_interface(void)
{
    char cmd[MAX_CMD_LEN];
    uint8_t  speed, current_sense;
    uint16_t ticks;
    uint16_t t;
    uint8_t  i, cs;

    for(i = 0; i < 5; i++)
    {
        set_led_rgb(0, 0, 255);
        _delay_ms(150);
        set_led_rgb(0, 0, 0);
        _delay_ms(150);
    }
    set_led_pattern(LED_PATTERN_IDLE);
    for(;;)
    {
        cli();
        g_reset = 0;
        g_current_sense_detected = 0;
        setup();
        stop_motor();
        serial_init();
        cs = 0;
        sei();

        _delay_ms(10);
        dprint("\nParty Robotics Dispenser at your service!\n\n");

        for(;;)
        {
            cli();
            cs = g_current_sense_detected;
            sei();
            if (!receive_cmd(cmd))
                break;

            if (sscanf(cmd, "speed %hhu %hhu", &speed, &current_sense) == 2)
            {
                if (!cs)
                    set_motor_speed(speed, current_sense);

                if (current_sense == 0)
                    flush_saved_tick_count(0);
                continue;
            }
            if (sscanf(cmd, "tickdisp %hu %hhu", (short unsigned int *)&ticks, &speed) == 2)
            {
                if (!cs)
                {
                    dispense_ticks(ticks, speed);
                    flush_saved_tick_count(0);
                }
                continue;
            }
            if (sscanf(cmd, "timedisp %hu", (short unsigned int *)&t) == 1)
            {
                if (!cs)
                {
                    run_motor_timed(t);
                    flush_saved_tick_count(0);
                }
                continue;
            }
            if (strncmp(cmd, "forward", 7) == 0)
            {
                set_motor_direction(MOTOR_DIRECTION_FORWARD);
                continue;
            }
            if (strncmp(cmd, "backward", 8) == 0)
            {
                set_motor_direction(MOTOR_DIRECTION_BACKWARD);
                continue;
            }
            if (strncmp(cmd, "led_idle", 8) == 0)
            {
                set_led_pattern(LED_PATTERN_IDLE);
                continue;
            }
            if (strncmp(cmd, "led_dispense", 12) == 0)
            {
                set_led_pattern(LED_PATTERN_DISPENSE);
                continue;
            }
            if (strncmp(cmd, "led_done", 8) == 0)
            {
                set_led_pattern(LED_PATTERN_DRINK_DONE);
                continue;
            }
            if (strncmp(cmd, "led_clean", 8) == 0)
            {
                set_led_pattern(LED_PATTERN_CLEAN);
                continue;
            }
            if (strncmp(cmd, "help", 4) == 0)
            {
                dprint("You can use these commands:\n");
                dprint("  speed <speed> <cs>\n");
                dprint("  tickdisp <ticks> <speed>\n");
                dprint("  timedisp <ms>\n");
                dprint("  forward\n");
                dprint("  backward\n");
                dprint("  reset\n");
                dprint("  led_idle\n");
                dprint("  led_dispense\n");
                dprint("  led_done\n");
                dprint("  led_clean\n\n");
                dprint("speed is from 0 - 255. cs = current sense and is 0 or 1.\n");
                dprint("ticks == number of quarter turns. ms == milliseconds\n");
                continue;
            }
            if (strncmp(cmd, "reset", 5) == 0)
                break;

            dprint("Unknown command. Use help to get, eh help. Duh.\n");
        }
    }
}

uint8_t address_exchange(void)
{
    uint8_t  ch;
    uint8_t  id, text_cmd = 0;

    set_led_rgb(0, 0, 255);
    id = eeprom_read_byte((uint8_t *)ee_pump_id_offset);
    if (id == 0 || id == 255)
    {
        // we failed to get a unique number for the pump. just stop.
        set_led_rgb(255, 0, 0);
        for(;;);
    }

    for(;;)
    {
        for(;;)
        {
            if (serial_rx_nb(&ch))
                break;

            if (check_reset())
                return 0xFF;
        }
        if (ch == 0xFF)
            break;
        if (ch == '?')
            serial_tx(id);
        if (ch == '!')
            text_cmd++;
        if (ch == '!' && text_cmd == 3)
            text_interface();
    }

    return id;
}
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
int main(void)
{
    uint8_t  id, rec, i, cs;
    color_t  c;
    packet_t p;

    setup();
    stop_motor();

    sei();
    for(i = 0; i < 5; i++)
    {
        set_led_rgb(255, 0, 255);
        _delay_ms(50);
        set_led_rgb(255, 255, 0);
        _delay_ms(50);
    }

    // Ensure we're running the right software for this board
    check_software_revision();

    // get the current liquid level 
    update_liquid_level();

    for(;;)
    {
        cli();
        g_reset = 0;
        g_current_sense_detected = 0;
        g_motor_direction = MOTOR_DIRECTION_FORWARD;
        setup();
        serial_init();
        stop_motor();
        pulse_motor_driver_retry();
        set_led_rgb(0, 0, 255);

        sei();
        id = address_exchange();

        for(; !check_reset();)
        {
            rec = receive_packet(id, &p);
            if (rec == COMM_CRC_FAIL)
                continue;

            if (rec == COMM_RESET)
                break;

            if (rec == COMM_OK && (p.dest == DEST_BROADCAST || p.dest == id))
            {
                // If we've detected a over current sitatuion, ignore all comamnds until reset
                cli();
                cs = g_current_sense_detected;
                sei();

                switch(p.type)
                {
                    case PACKET_PING:
                        break;

                    case PACKET_GET_VERSION:
                        send_packet8(PACKET_GET_VERSION, SOFTWARE_VERSION);
                        break;

                    case PACKET_SET_MOTOR_SPEED:
                        if (!cs)
                            set_motor_speed(p.p.uint8[0], p.p.uint8[1]);

                        if (p.p.uint8[0] == 0)
                            flush_saved_tick_count(0);
                        break;

                    case PACKET_SET_MOTOR_DIRECTION:
                        if (!cs)
                            set_motor_direction(p.p.uint8[0]);

                        break;

                    case PACKET_TICK_DISPENSE:
                        if (!cs)
                        {
                            dispense_ticks((uint16_t)p.p.uint32, 255);
                            flush_saved_tick_count(0);
                        }
                        break;

                    case PACKET_TIME_DISPENSE:
                        if (!cs)
                        {
                            run_motor_timed((uint16_t)p.p.uint32);
                            flush_saved_tick_count(0);
                        }
                        break;

                    case PACKET_IS_DISPENSING:
                        is_dispensing();
                        break;

                    case PACKET_LIQUID_LEVEL:
                        get_liquid_level();
                        break;

                    case PACKET_UPDATE_LIQUID_LEVEL:
                        update_liquid_level();
                        break;

                    case PACKET_LED_OFF:
                        set_led_pattern(LED_PATTERN_OFF);
                        break;

                    case PACKET_LED_IDLE:
                        if (!cs)
                            set_led_pattern(LED_PATTERN_IDLE);
                        break;

                    case PACKET_LED_DISPENSE:
                        if (!cs)
                            set_led_pattern(LED_PATTERN_DISPENSE);
                        break;

                    case PACKET_LED_DRINK_DONE:
                        if (!cs)
                            set_led_pattern(LED_PATTERN_DRINK_DONE);
                        break;

                    case PACKET_LED_CLEAN:
                        if (!cs)
                            set_led_pattern(LED_PATTERN_CLEAN);
                        break;

                    case PACKET_COMM_TEST:
                        comm_test();
                        break;

                    case PACKET_ID_CONFLICT:
                        id_conflict();
                        break;

                    case PACKET_SET_CS_THRESHOLD:
                        // Only for v2 pumps
                        break;

                    case PACKET_SAVED_TICK_COUNT:
                        get_saved_tick_count();
                        break;

                    case PACKET_RESET_SAVED_TICK_COUNT:
                        reset_saved_tick_count();
                        break;

                    case PACKET_FLUSH_SAVED_TICK_COUNT:
                        flush_saved_tick_count(1);
                        break;

                    case PACKET_GET_LIQUID_THRESHOLDS:
                        get_liquid_thresholds();
                        break;

                    case PACKET_SET_LIQUID_THRESHOLDS:
                        set_liquid_thresholds(p.p.uint16[0], p.p.uint16[1]);
                        break;

                    case PACKET_TICK_SPEED_DISPENSE:
                        if (!cs)
                        {
                            dispense_ticks(p.p.uint16[0], (uint8_t)p.p.uint16[1]);
                            flush_saved_tick_count(0);
                        }
                        break;
                    case PACKET_PATTERN_DEFINE:
                        pattern_define(p.p.uint8[0]);
                        break;

                    case PACKET_PATTERN_ADD_SEGMENT:
                        c.red = p.p.uint8[0];
                        c.green = p.p.uint8[1];
                        c.blue = p.p.uint8[2];
                        pattern_add_segment(&c, p.p.uint8[3]);
                        break;

                    case PACKET_PATTERN_FINISH:
                        pattern_finish();
                        break;
                }
            }
        }
    }
    return 0;
}

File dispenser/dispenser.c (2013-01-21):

#include <avr/io.h>
#include <avr/interrupt.h>
#include <util/delay.h>

#include <stddef.h>
#include <math.h>
#include <stdio.h>
#include <stdlib.h>
#include <string.h>
#include <avr/eeprom.h>
#include <stdarg.h>
#include <stdlib.h>
#include "defs.h"

#include "packet.h"
#include "serial.h"
#include "led.h"

#if F_CPU == 16000000UL
#define    TIMER1_INIT      0xFFEF
#define    TIMER1_FLAGS     _BV(CS12)|(1<<CS10); // 16Mhz / 1024 / 16 = .001024 per tick
#else
#define    TIMER1_INIT      0xFFF7
#define    TIMER1_FLAGS     _BV(CS12)|(1<<CS10); // 8Mhz / 1024 / 8 = .001024 per tick
#endif

// TODO
// Re-add LED patterns & code LED patterns without floating point math
// Add support for different animation speeds

// Production TODO:
// Hook up more RX pins
// Move Sync to different pin

// EEprom data 
uint32_t EEMEM _ee_pump_id;
uint32_t EEMEM _ee_run_time;

#define RESET_DURATION  1
#define SYNC_COUNT      10 // Every SYNC_INIT ms we will change the color animation
#define NUM_ADC_SAMPLES 5
#define NUM_CURRENT_SENSE_SAMPLES 10

volatile uint32_t g_time = 0;
static volatile uint32_t g_reset_fe_time = 0;
static volatile uint32_t g_reset = 0;
static volatile uint32_t g_ticks = 0;
static volatile uint32_t g_dispense_target_ticks = 0;
static volatile uint8_t g_is_dispensing = 0;
static volatile uint16_t g_liquid_level = 0;

static volatile uint8_t g_hall0 = 0;
static volatile uint8_t g_hall1 = 0;
static volatile uint8_t g_hall2 = 0;
static volatile uint8_t g_hall3 = 0;
static volatile uint8_t g_sync = 0;
static volatile uint32_t g_sync_count = 0, g_pattern_t = 0;
static void (*g_led_function)(uint32_t, color_t *) = 0;

void check_dispense_complete_isr(void);
void set_motor_speed(uint8_t speed);

/*
   0  - PD0 - RX
   1  - PD1 - TX
   2  - PD2 - RESET
   3  - PD3 - LED clock
   4  - PD4 - LED data
   5  - PD5 - motor PWM out
   6  - PD6 - Hall 0 (pcint 22)
   7  - PD7 - Hall 1 (pcint 23)
   8  - PB0 - Hall 2 (pcint 0)
   9  - PB1 - Hall 3 (pcint 1) 
  10  - PB2 - SYNC (pcint 2)
  A0  - PC0 - CS
  A1  - PC1 - liquid level

*/
void setup(void)
{
    // Set up LEDs & motor out
    DDRD |= (1<<PD3)|(1<<PD4)|(1<<PD5);

    // pull ups
    sbi(PORTD, 6);
    sbi(PORTD, 7);
    sbi(PORTB, 0);
    sbi(PORTB, 1);

    // Timer setup for reset pulse width measuring
    TCCR1B |= TIMER1_FLAGS;
    TCNT1 = TIMER1_INIT;
    TIMSK1 |= (1<<TOIE1);

    // Set to Phase correct PWM, compare output mode
    TCCR0A |= _BV(WGM00) | _BV(COM0B1);

    // Set the clock source
    TCCR0B |= (0 << CS00) | (1 << CS01);

    // Reset timers and comparators
    OCR0B = 0;
    TCNT0 = 0;

    // INT0 for router reset
    EICRA |= (1 << ISC00);
    EIMSK |= (1 << INT0);

    // PCINT setup
    PCMSK0 |= (1 << PCINT0) | (1 << PCINT1) | (1 << PCINT2);
    PCMSK2 |= (1 << PCINT22) | (1 << PCINT23);
    PCICR |=  (1 << PCIE2) | (1 << PCIE0);
}

// update g_time
ISR (TIMER1_OVF_vect)
{
    g_time++;
    TCNT1 = TIMER1_INIT;
}

// reset pin change
ISR(INT0_vect)
{
    if (PIND & (1<<PIND2))
    {
        g_reset_fe_time = g_time + RESET_DURATION;
    }
    else
    {
        if (g_reset_fe_time > 0 && g_time >= g_reset_fe_time)
            g_reset = 1;
        g_reset_fe_time = 0;
    }
}

ISR(PCINT0_vect)
{
    uint8_t      state;

    state = PINB & (1<<PINB0);
    if (state != g_hall2)
    {
        g_hall2 = state;
        g_ticks++;
    }

    state = PINB & (1<<PINB1);
    if (state != g_hall3)
    {
        g_hall3 = state;
        g_ticks++;
    }
    check_dispense_complete_isr();

    state = PINB & (1<<PINB2);
    if (state != g_sync)
    {
        g_sync_count++;
        g_sync = state;
    }
}

ISR(PCINT2_vect)
{
    uint8_t state;

    state = PIND & (1<<PIND6);
    if (state != g_hall0)
    {
        g_hall0 = state;
        g_ticks++;
    }

    state = PIND & (1<<PIND7);
    if (state != g_hall1)
    {
        g_hall1 = state;
        g_ticks++;
    }
    check_dispense_complete_isr();
}

// this function is called from an ISR, so no need to turn off/on interrupts
void check_dispense_complete_isr(void)
{
    if (g_dispense_target_ticks > 0 && g_ticks >= g_dispense_target_ticks)
    {
         g_dispense_target_ticks = 0;
         g_is_dispensing = 0;
         set_motor_speed(0);
    }
}

uint8_t check_reset(void)
{
    uint8_t reset;

    cli();
    reset = g_reset;
    sei();

    return reset;
}

void idle(void)
{
    color_t c;
    uint8_t animate = 0;
    uint32_t t = 0;

    cli();
    if (g_sync_count >= SYNC_COUNT)
    {
        g_sync_count = 0;
        animate = 1;
    }
    sei();

    if (animate && g_led_function)
    {
        cli();
        t = g_pattern_t++;
        sei();
        // do some animation!
        (*g_led_function)(t, &c);
        set_led_rgb_no_delay(c.red, c.green, c.blue);
    }
}

void set_led_pattern(void (*func)(uint32_t, color_t *))
{
    if (func == NULL)
        set_led_rgb(0, 0, 0);

    cli();
    g_pattern_t = 0;
    sei();
    g_led_function = func;
}

void adc_liquid_level_setup(void)
{
    ADCSRA = (1 << ADPS1);
    ADMUX = (1<<REFS0) | (1 << MUX0);
    ADCSRA |= (1<<ADEN);
}

void adc_current_sense_setup(void)
{
    ADCSRA = (1 << ADPS0) | (1 << ADPS1) | (1 << ADPS2);
    ADMUX = (1<<REFS0) | (0 << REFS1);
    ADCSRA |= (1<<ADEN);
}

void adc_shutdown(void)
{
    ADCSRA &= ~(1<<ADEN);
}

uint16_t adc_read()
{
    uint8_t hi, low;

    ADCSRA |= (1<<ADSC);
    while(ADCSRA & 0b01000000);
    low = ADCL;
    hi = ADCH;
    return (hi << 8) | low;
}

uint16_t read_current_sense(void)
{
    uint8_t  i;
    uint16_t v = 0;

    adc_current_sense_setup();
    for(i = 0; i < NUM_CURRENT_SENSE_SAMPLES; i++)
        v += adc_read();
    adc_shutdown();

    return (uint16_t)(v / NUM_CURRENT_SENSE_SAMPLES);
}

uint16_t read_liquid_level_sensor(void)
{
    uint8_t  i;
    uint16_t v = 0;

    adc_liquid_level_setup();
    for(i = 0; i < NUM_ADC_SAMPLES; i++)
        v += adc_read();
    adc_shutdown();

    return (uint16_t)(v / NUM_ADC_SAMPLES);
}

void liquid_level(void)
{
    send_packet16(PACKET_LIQUID_LEVEL, read_liquid_level_sensor());
}

void set_motor_speed(uint8_t speed)
{
    OCR0B = 255 - speed;
}

void run_motor_timed(uint32_t duration)
{
    uint32_t t;

    set_motor_speed(255);
    for(t = 0; t < duration && !check_reset(); t++)
        _delay_ms(1);
    set_motor_speed(0);
}

void dispense_ticks(uint32_t ticks)
{
    uint8_t dispensing;

    cli();
    dispensing = g_is_dispensing;
    sei();

    if (dispensing)
        return;

    cli();
    g_dispense_target_ticks = ticks;
    g_ticks = 0;
    g_is_dispensing = 1;
    sei();

    set_motor_speed(255);
}

void is_dispensing(void)
{
    uint8_t dispensing;

    cli();
    dispensing = g_is_dispensing;
    sei();

    send_packet8(PACKET_IS_DISPENSING, dispensing);
}

uint8_t read_pump_id_from_eeprom(void)
{
    return eeprom_read_byte((uint8_t *)0);
}
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

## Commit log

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2011-06-05 changed booze list from a pull-down, fixed cancel button
2011-06-06 Fixed submit buttons and page titles
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2011-10-15 This is a known good version of the database. This file should always agree with the current schema in git.
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2011-10-15 Fixing problems with slow comms, debugging detecting when a drink is done. Drink ingredients are now pushed to the template in an array
    [driver.py]
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2011-10-15 Added a standalone driver script and fixed up some mixer issues
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2011-12-17 Adding the first cut of a dispenser. SPI communications and addressing are working.
2011-12-17 Added error checking to ensure that the packet we send is the packet we get back. Sometimes the last byte in the packet gets corrupted, so as a quick fix, I made the packet one byte longer and dont u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
    [dispenser.c, master.c, packet.h]
2011-12-18 All the dispenser sub-systems are working! PWM control is fully working for each dispenser.
2011-12-20 Serial to SPI communications and various other SPI communication bugs have been fixed.
    [dispenser.c, driver.py, master.c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]
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2011-12-22 Making drinks works from the UI perspective. Now to actually drive the motors correctly.
    [driver.py]
2011-12-23 Removed PWM support from the motors, in favor of adding a timed dispense function. Also added a check function to see if the dispenser is dispensing or not.
2011-12-30 Set the motor driver pins correctly
    [dispenser.c]
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2012-02-05 Checked and corrected for buffer overruns. Implemented broadcast address. Implemented ping
    [dispenser.c]
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2012-02-07 Add a BARTENDRO_SOFTWARE_ONLY environment variable to have the software not talk to the hardware. Updated driver.py for new chain command messages Added led support to dispensers
2012-02-08 Added the missing newlines to the dispenser. Removed debug blinks. Fixed template for drink making
    [dispenser.c]
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2012-02-25 Fixed taster button.
2012-02-27 Added logging support and web support for viewing logs. Added logging messages to mixer. Added support for pinging/resetting the chain after making a drink.
    [driver.py]
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2012-02-29 Added one command cleaning fix
    [dispenser.c]
2012-03-02 Added logging of the communications to track errors
    [driver.py]
2012-03-02 Tweaks and fixes for barbot 2012
    [driver.py]
2012-03-02 Added support for calibrating each pump. Various debugging tweaks. Getting ready for BarBot 2012. Its late a night. Where is my bed?
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2012-03-28 Changed GPIO pin. Added a script that toggles the SS/reset pin Some debugging stuff to for testing tick based dispensing
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2012-05-02 Finished implementing and debugging the object model changes for taco de mayo.
2012-05-09 Fixed a floating point conversion error that made small dispenses freak out our dispensers. Also fixed taster button
2012-05-09 Implemented a simple hack for flashing the green leds after making a drink. Not thread safe, but should be fine for Taco dy Mayo.
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2012-05-12 Set title for the home page. More data fixes for Taco de Mayo
2012-06-01 Clear the chache when resetting the chain
2012-06-01 Tweaking startup issues and improving start scripts. And added support for user button reset
2012-06-01 Fixed minor problems and got new led lights working.
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2012-06-29 Use hall sensor 2, one of the pumps has a busted sensor #1
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2012-07-11 Strange bug exists where the led stick is disturbed when the PWM is enabled. Its fine otherwise.
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2012-10-04 Fixed wrong function name
    [dispenser.c]
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2012-10-28 Master reset function implemented
    [master.c]
2012-10-28 And also initialize the PCMSK registers correctly
    [master.c]
2012-10-28 Minor tweaks needed to fix a few things after the first liquid out changes.
    [driver.py]
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2012-10-28 Checking in few bug fixes for the liquid out sensor
    [driver.py]
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2012-11-30 Added support for dispensers being in a warning state. Added support for the diagnostic LED being set.
2012-11-30 Retry after timeout errors
    [driver.py]
2012-12-12 made changes to Router (swapped SYNC & RX14) removed extra resets, added ground to pin 22
    [RouterR1.sch]
2012-12-14 Interim check-in. Soft reset implemented. ID discovery half implemented
    [dispenser.c, master.c]
2012-12-14 Almost working dispenser id assignment. Still some bugs, but sometimes it works!
    [dispenser.c, master.c, packet.h]
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2012-12-22 Correct implementation of reading the 4 hall sensors
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2012-12-27 General house cleaning on the codebase. Moved timer interrupt to timer0 and have automatically adjust for different clock speeds Add ADC reading code for CS and liquid level Added PWM output motor co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
2012-12-29 Updated Router with the latest pinouts from Rob after breadboard testing 12/28/12
    [Router.brd, Router.sch]
2012-12-29 Start transmit lines pulled up. Harmonize clock settings and use 1ms timer resolution. Add SYNC support. SYNC, when on, has the twice the frequency of the timer in the master (2ms)
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2013-01-01 Added Dispenser Schematic and Layout
    [Dispenser.brd, Dispenser.sch, Router.brd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]
2013-01-02 Adding routings for production boards and moved SYNC to correct pin. Implemented and partially debugged LED setting. There are still some communication bugs that need to be figured out, otherwise its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
    [dispenser.c, led.h, master.c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]
2013-01-02 Reverted back to the clunky, but super fast way of routing pin changes
    [master.c]
2013-01-02 Re-factored the ISR to be ready for more dispensers. The current structure is fast, but a little ugly to read. In theory it should not get any slower to add more dispensers. In theory!
2013-01-02 The code that reset g_pattern_t when a new pattern was set was lost. :(
    [dispenser.c]
2013-01-03 Updated Router Schematic with DS1307 and Accessory Port
    [Dispenser.brd, Dispenser.sch, Router.brd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]
2013-01-03 Updated inputs to opto-isolator
    [Dispenser.brd, Dispenser.sch]
2013-01-03 Dispener updates
    [Dispenser.brd, Dispenser.sch]
2013-01-03 Current sense cap to 100u, and opto inputs changed again
    [Dispenser.brd, Dispenser.sch]
2013-01-03 removed LED_DATA pull up
    [Dispenser.brd, Dispenser.sch]
2013-01-04 Commiting updated SCH and BRD
    [Router.brd, Router.sch]
2013-01-04 Finished Dispenser Layout!
    [Dispenser.brd, Dispenser.sch]
2013-01-04 Finished Router Layout!
    [Router.brd, Router.sch]
2013-01-04 cleaned up dispenser layout silkscreen and design rules.
    [Dispenser.brd, Dispenser.sch]
2013-01-04 Final files that were used to CAM dispenser and router boards
    [Dispenser.brd, Router.brd, Router.sch]
2013-01-07 Added Pump to RX mappings on the router schematic
    [Router.sch]
2013-01-07 Updated to schematic and layout to Rev 1.1 (PD0 and PD1 swapped)
    [Router.brd, Router.sch]
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2013-01-09 New method for sending packets works. LEDs confuse things, so they are turned off for now.
2013-01-15 Implemented dispensers sending packets to the master. Some packing/crc issues remain to be worked out.
    [dispenser.c, packet.h]
2013-01-18 Fix packing problem, remove some debug info
    [master.c, packet.h]
2013-01-18 Fix pump 2
2013-01-18 Fixed the comms issue with the RPI. The new router had rx/tx reversed
    [master.c]
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2013-01-18 Fixed all of the mappings in the router
    [master.c]
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2013-01-20 Things are horribly broken. Fuss!
    [dispenser.c]
2013-01-20 Reset before setup doesn't work. :)
    [dispenser.c, master.c]
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2013-01-21 Fix I2C error
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2013-01-23 Hard coding ids. Done a bunch of debugging on the router But we can now control 7 pumps!
2013-02-02 Inititalize the outpout lines more intelligently. This should hopefully reduce the transmission errors on startup.
    [router.c]
2013-02-03 Refactored the code to allow the hardware specific things like i2c and status led to be missing for the software_only mode
    [dispenser_select.py, driver.py, status_led.py]
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2013-02-06 Various logic and syntax errors fixed that I could't run on the plane
    [dispenser_select.py, driver.py]
2013-02-11 Random bits of debugging to try and figure out the pump id issues
    [dispenser.c, dispenser_select.py, driver.py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]
2013-02-12 Created MiniRouter board Rev 1. Added schematic and layout.
    [Dispenser.brd, MiniRouter.brd, MiniRouter.sch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]
2013-02-13 Fixed a copy pasta problem -- all the ports seem to work now.
    [router.c]
2013-02-13 Added and tested pump id collision support
    [dispenser.c, driver.py, packet.h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]
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2013-02-13 If you plug your pumps in from the lowest number, things are great!
2013-02-16 Fixed for v2 of RPI
    [dispenser_select.py]
2013-02-16 Initialize the dispenser select for the first time. Also just show 7 pumps while debugging #7
2013-02-16 Swtich to RPI v2 (again) and do a proper reset by reopening everything
    [dispenser_select.py, driver.py]
2013-02-16 Random bits of debugging and checking. Still no idea why SYNC fails.
    [dispenser_select.py, driver.py, router.c]
2013-02-17 First cut at using twitter bootstrap with the new design on the menu page
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2013-02-27 Minor liquid out fixes
    [driver.py]
2013-02-27 Some more UI tweaks to enable disable buttons Tweaked ticks per ml Changed status led color to blue, yellow, red
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2013-02-28 Ignore what the out column in dispenser says when we're not using liquid out sensors.
2013-02-28 Show an error dialog for the taster/make drink button if the user is not logged in.
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2013-03-11 Added support for swapping the mini router board mappings
    [driver.py]
2013-03-17 Implemented a clean cycle and updated LED patterns a little beyond hello world type patterns. :)
2013-03-17 Minor UI tweaks. Set clean duration to 30 second per pump, 5 pumps max
2013-04-28 Improved the error handling of I2C and Serial errors including better error messages, including hints on how to enable software only mode.
    [dispenser_select.py, driver.py]
2013-05-16 Do not retry packets three times. Just report an error. Fixes #12
    [driver.py]
2013-05-16 Finished fixing a communication problem when pumps were not plugged in sequentially.
    [driver.py]
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2013-05-26 Implmented current sense in the pump. If a pump senses an over current situation for more than 3 cycles, it will stop the pump, make the LEDs flash red and ignore all pump related commands until a re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
    [dispenser.c, led.h, packet.h]
2013-05-31 Fixed the pinouts for status leds on the new router boards
    [status_led.py]
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2013-06-04 Removed defines that were no longer used
    [packet.h]
2013-06-04 Added must_login_to_dispense configuration. All WS function that may turn the motors must now check this setting and be logged in if the setting is true
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2013-06-11 Checking in the final dispenser schematics for the kickstarter dispensers
    [Dispenser.brd, Dispenser.sch]
2013-06-11 Checking in the latest schematics for the kickstarter
    [MiniRouter.brd, MiniRouter.sch, Router.brd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]
2013-06-19 Options table now gets created and default options inserted into the table.
2013-06-22 Fixed the green<->blue LED swap on the dispenser
2013-06-23 Firmware fix for issue #15. Ensure that any dispense command is > 0. :)
    [dispenser.c]
2013-06-24 Reworked all LED patterns to use new fade from point to point led system that will soon be user programmable!
    [dispenser.c, led.h]
2013-06-24 Implemented over current sense for simply turning the motor on/off. Against my own judgement.
2013-06-24 the is dispensing command now includes a report on current sense. dispenser documentation has been updated to reflect the improved current sense support.
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2013-07-03 Removed the calibration dispense text field from the dispenser page. Changed the test dispense button to be configurable from config.py, default 10ml. Also, use a shorter timeout for is_dispensing co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
    [driver.py]
2013-07-03 Which cancel button? Fixes #29
2013-07-03 Reload the dispenser page after hitting reset to ensure correct button states. Fixes #41
2013-07-07 Committing a couple of software only mode issues
    [driver.py]
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2013-07-27 Return proper number of arguments, even during an error
    [driver.py]
2013-07-28 Checking in Issue #64 migitation code. Still no idea what causes that.
    [driver.py]
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2013-07-28 Missed on _send_packet8 reference
    [driver.py]
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2013-07-31 Ignore the out values in the dispenser table when liquid sensors are turned off. Fixes #63
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2013-08-08 Added a screwdriver. Fixes #69
2013-08-11 Change router scheme to always echo
    Some logic is hard to prove right. This patch changes router.c to 'be stupider' instead. Any time a data interrupt is taken, we do all possible things that could be related. For PC_INT0, we echo the rPi outward and the current dispenser back toward the rPi.
    Note, even if the current dispenser is tied to INT1, when INT0 fires we still read the current state of our target dispenser line, and set the outbound to the same level. This will cause extra work (due to extraneous interrupts), but is shorter and easier to argue correct.
    [router.c]
2013-08-12 The workaround is an *actual* fix. Except that we now understand it!
    [dispenser_select.py]
2013-08-14 Fixed typo. Fixed taster button.
2013-08-14 Improve a lot of error logging and status messages. Fixes #13
    [driver.py]
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2013-08-14 Make sure the button states in the dispenser always reflect reality. Fixes #48
2013-08-14 The turn on/off and test dispense buttons now correctly handle over current cases
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2013-08-15 Added a nicer dialog to the dispenser page and fixed dispenser page button layout. Fixes #71
2013-08-15 Add a back button to the error message
2013-11-02 Interim check-in. Booze planner not working yet.
    [driver.py]
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2014-01-11 Changed save button to "save and reboot" indicating that Barentdro will reboot after a options change.
2014-01-11 Changed the reset button to say "reset dispenser"
2014-01-11 Do not show drink related things when we only have one pump. Fixes #83
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2014-01-14 Finished making button colors consistent. Fixes #106
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2014-01-15 Ensure that 0ml doesn't even get communicated to pumps. Ensure that dispenses less than 20ml are done slowly to be more accurate.
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2014-01-17 Fixed up the hall sensors, sync and current sense functions for v3 dispenser.
    [dispenser.c]
2014-01-17 Reverse is not implemented yet, but everything else could work.
    [dispenser.c]
2014-01-17 Finished porting changes to the v3 board. Reverse is not implemented yet.
    [dispenser.c]
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2014-01-17 Fixed one merge goof
    [dispenser.c]
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2014-01-22 Use the correct pump left/right mapping
2014-01-22 Fixed a couple of minor issues, but uncovered a few more issues. The mixer needs more of a re-write. :(
2014-02-04 Swap blue<->green since we're using a different LED.
2014-02-04 A motor driver reset test
    [dispenser.c]
2014-02-04 Set the retry line correctly at the start
    [dispenser.c]
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2014-02-22 Fixed crash when no wired connection is present
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2014-03-27 Basic FSM functions are working, lots of error handling clean up (not done) and adding 3 custom LED states
    [dispenser.c, driver.py, led.h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]
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2014-03-27 Tweak packet numbers to not clash with v3 pumps. Tuned red flashing error state.
    [driver.py, packet.h]
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2014-03-31 Fix cleaning related errors. Fixes #130
    [driver.py]
2014-03-31 Interim check-in. Adding reverse support to ui
    [driver.py]
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2014-04-02 Massive debugging. Shots now work properly and behave correctly when they run out of stuff.
    [driver.py]
2014-04-08 Fixed curious errors to a couple of exceptions
    [dispenser_select.py, driver.py]
2014-04-17 Fix pump rollover issue
2014-04-22 Added support for properly enabling and disabling buttons on the dispenser page. Fixes #146
2014-04-22 Fixed leds after clean. Make the Bartendro logo in the admin go to the menu
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2014-04-23 Found another case where the motor could spin backwards. Also fixed silent taster button fails. Fixes #134
2014-05-13 Swapping blue/green for the router/led fuck up
    [status_led.py]
2014-05-14 Added a more robus fix for the blue/green swap
    [driver.py, status_led.py]
2014-05-14 Minor fix to the green/blue swap
    [driver.py, status_led.py]
2015-01-04 Put the old error message back.
    [dispenser.c]
2015-01-11 Improved error messages that mention which dispenser is giving trouble. This should help with identifying if a bot had bad dispensers.
    [driver.py]
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2015-01-11 If a dispense command fails, retry it once
    [driver.py]
2015-01-11 Retry router comm errors once before going into error state
    [dispenser_select.py]
2016-03-07 Flask-Login changed is_authenticated() from a method to a property. This change fixes Bartendro to work with current Flask-Login.
2016-10-05 Fix one error message and then update the UWSI sharedareas API
    [dispenser_select.py]
2016-10-05 Fix more error messages.
    [dispenser_select.py]
2016-10-10 Undo the blue/green swap again. Inc software version.
    [dispenser.c]
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2016-10-22 Reapply fixes from the olli-branch that somehow got lost
    [driver.py]

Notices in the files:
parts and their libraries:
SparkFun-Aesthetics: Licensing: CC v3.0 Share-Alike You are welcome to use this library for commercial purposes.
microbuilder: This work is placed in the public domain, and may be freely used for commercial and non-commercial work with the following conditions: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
